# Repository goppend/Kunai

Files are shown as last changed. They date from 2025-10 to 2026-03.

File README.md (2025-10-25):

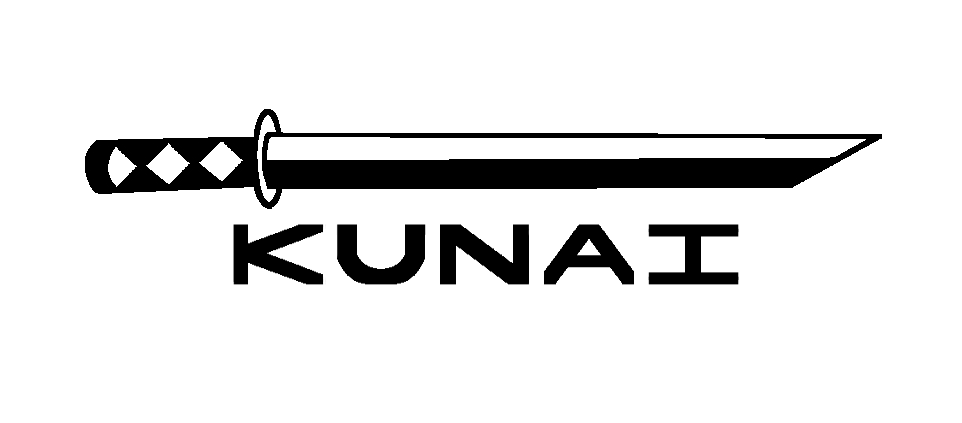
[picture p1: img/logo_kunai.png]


The Kunai is an open source gamepad based on the Raspberry Pi Pico microcontroller.

Its intended use is either as a standalone controller for Playstation and Playstation 2 systems, or integrated into an all-in-one handheld device that uses the aforementioned systems hardware.

Features
---
- A no-compromises approach to emulating the original functions of the Dualshock 2 gamepad.
- 12 inputs that can be configured as either digital or pressure-sensitive analog buttons.
- 2 rumble motor outputs capable of being driven at 256 pulse-width modulated levels.
- Compatible with readily available aftermarket joysticks. Hall-effect joysticks have yet to be tested, but may be compatible.

Compatibility
---
Not enough testing has been performed to discover any major incompatibilities yet, but as the project evolves, this section will be populated with a list of known good and ill-working titles and applications.

To-do
---
Currently, this project is exiting the "functional prototype" phase, and is not especially useful for gaming, but this will change soon. 
- Shrink the prototype PCB down to work as a drop-in replacement for Dualshock controllers.
- Develop a module as small as possible for rapid integration into custom handheld projects. Version 0 of the module has been released! Check it out in the pcb-module directory.

Attribution
---
[Dangiu/PicoMemcard](https://github.com/dangiu/PicoMemcard/) - Credit for the PIO code responsible for doing gamepad/console communication.

[Loc15/PicoGamepadConverter](https://github.com/Loc15/PicoGamepadConverter/) - Much inspiration for this project, and the multi-core implementation.

[GameSX](https://gamesx.com/controldata/psxcont/psxcont.htm) and [Curious Inventor](https://store.curiousinventor.com/guides/PS2)- Excellent documentation on the protocol and data structures.

Ultipryce - Logo artwork.
___
Disclaimer

This is a passion project by a fan and has no affiliation with Sony or the Playstation brand.

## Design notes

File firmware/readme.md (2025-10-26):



## Kunai Firmware
This is the first release of the Kunai Firmware. Only one of its operating modes is mostly complete, and needs more and better testing.

### Building
---
- I recommend using VSCodium with the official Raspberry Pi Pico extension and the latest SDK.
- Open this folder.
- Optionally, edit config.h to suit the hardware.
- Compile.
- Two UF2 artifacts are created in the `build/` directory, `kunai.uf2` for the main PCB, and `kunai-mod.uf2` for the Kunai module.

### Configuration
---
In `config.h`, there are some defines that can be changed to alter the behavior of the Kunai:
- `DIGITAL_INPUTS` If defined, the Kunai will treat inputs as digital button presses rather than analog values from pressure sensors, akin to a Dualshock 2.
- `GPIO_*` The digital I/O pins connected to the Pico. By default, these are tailored to suit the version 0 of either hardware implementation.
- `SPI_*` The pins connected to an SPI analog-to-digital converter, to gather the analog pressure inputs. When configured to be digital-only, these pins are undefined.
- If so desired, changing the host `ACK`, `CLK`, `ATN`, `CMD`, and `DAT` pins requires modification of either of the two `psx-device/psxSPI*.pio` files.

### Future Development
---
- Add proper digital-only input methods. (testing in progress)
- Add a pseudo-analog mode for digital-only hardware to support software that requires analog input.
- Analog/digital mode switching is unimplemented. Not entirely sure how to do this.
- Extensive testing will be needed once the hardware is ready.

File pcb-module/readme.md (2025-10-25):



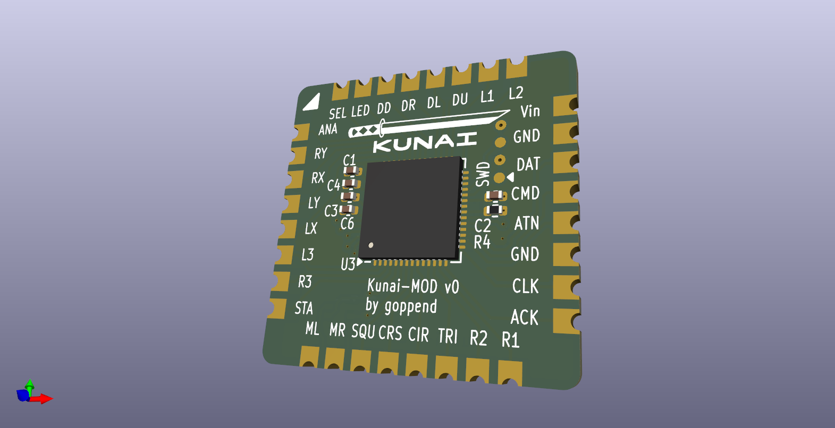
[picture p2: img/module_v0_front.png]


## Module PCB
This is the Kunai, but in a 22 mm x 22 mm module. The intent is to provide a solution for rapid integration into exiting projects. Thus, most of the I/O is dedicated towards direct connections to discrete buttons, though there's no reason a connection to an ADC couldn't be made just like a full-sized Kunai.

There is KiCad footprint `kunai-mod.kicad_mod` available in the root of this directory, which contains the general pinout compatible with the module.

### Future Development
---
- An integration guide for this module. This document will detail the steps necessary to get as much out of the Kunai as possible for your project.
- HD rumble motors as a potential upgrade via e.g. the DRV2603, which is compatible with LRA as well as traditional ERM rumble motors.

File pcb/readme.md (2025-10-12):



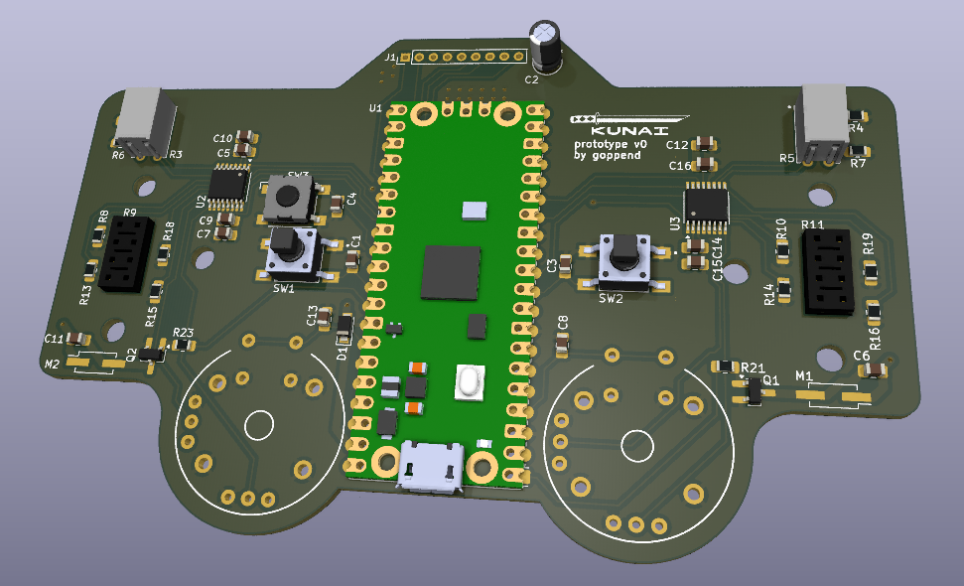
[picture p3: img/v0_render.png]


## Prototype PCB
This is the first release of the Kunai PCB. It's a functional prototype, and as such isn't recommended for gaming yet.

A few things to keep in mind, for anyone interested in building one:
- I have no enclosure designed yet, but the general button layout is 1:1 with an original Dualshock 2.
- The rectangular connectors were for testing, to easily swap a pressure sensor from one spot to another. I would not recommend using these connectors and instead replace the footprint with a normal soldered footprint since that portion of the testing is complete.

### Future Development
---
- Replace aftermarket PS2 joysticks with PS4 since hall effect versions with that footprint exist.
- Replace the Pico with a RP2040.

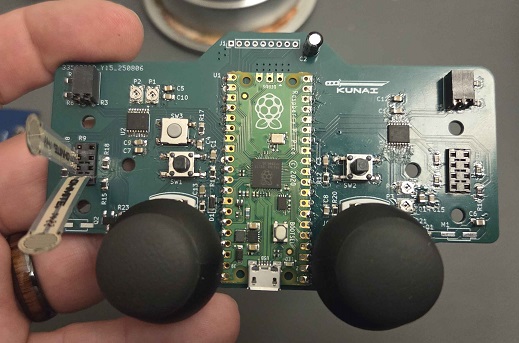
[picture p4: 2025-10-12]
img/prototype.jpg

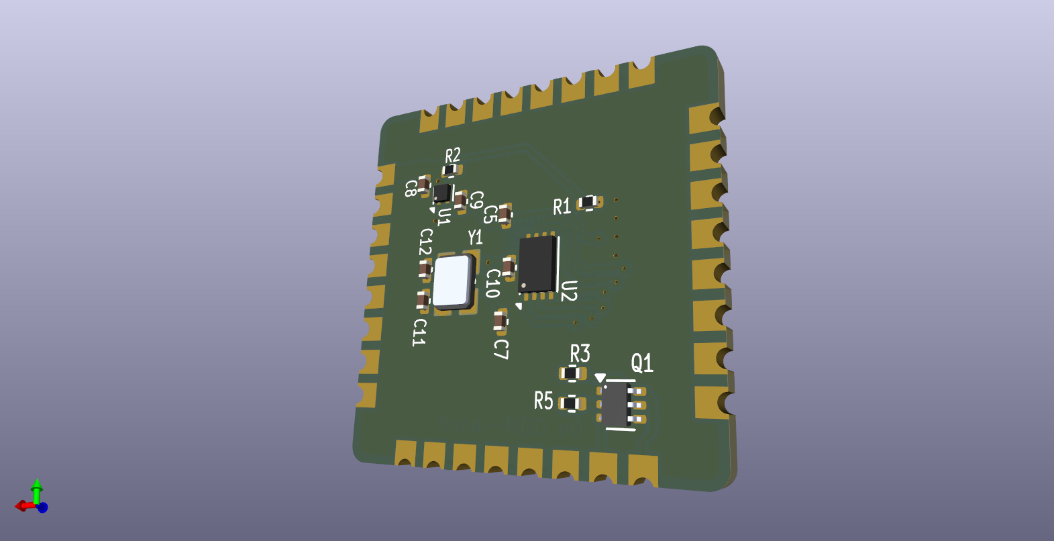
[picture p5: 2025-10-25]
img/module_v0_back.png

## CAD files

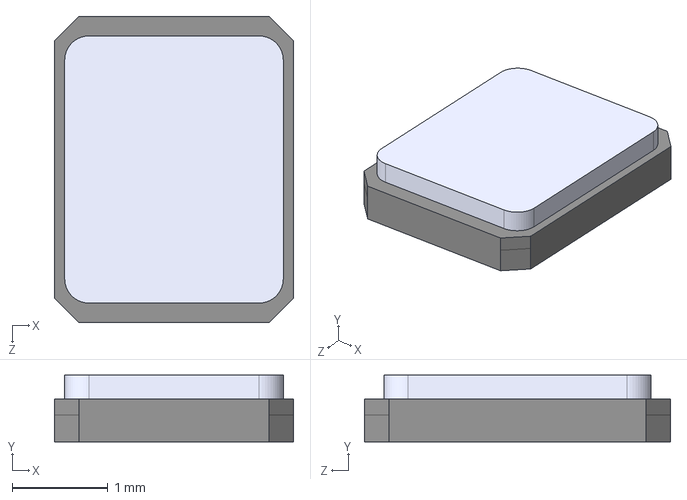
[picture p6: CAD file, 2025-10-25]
pcb-module/3d-models/ABM8-272-T3.step
2.50 x 0.7 x 3.20 mm

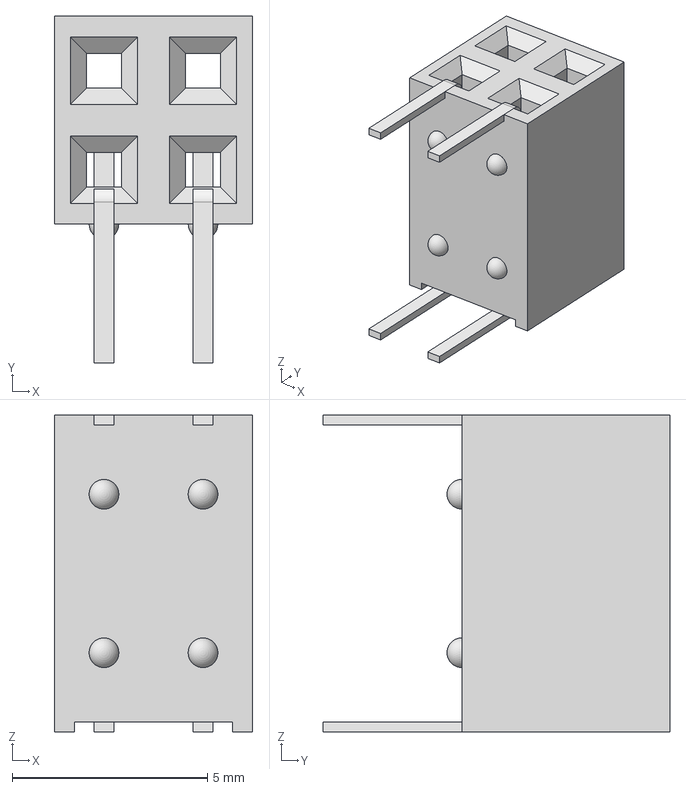
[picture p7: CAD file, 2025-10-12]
pcb/3d-models/BCS-102-L-D-HE.stp
5.08 x 8.89 x 8.13 mm
BCS-102-D-HE_socket
C-95-01-02-L-D-HE
C-95-01-02-L-D-HE2

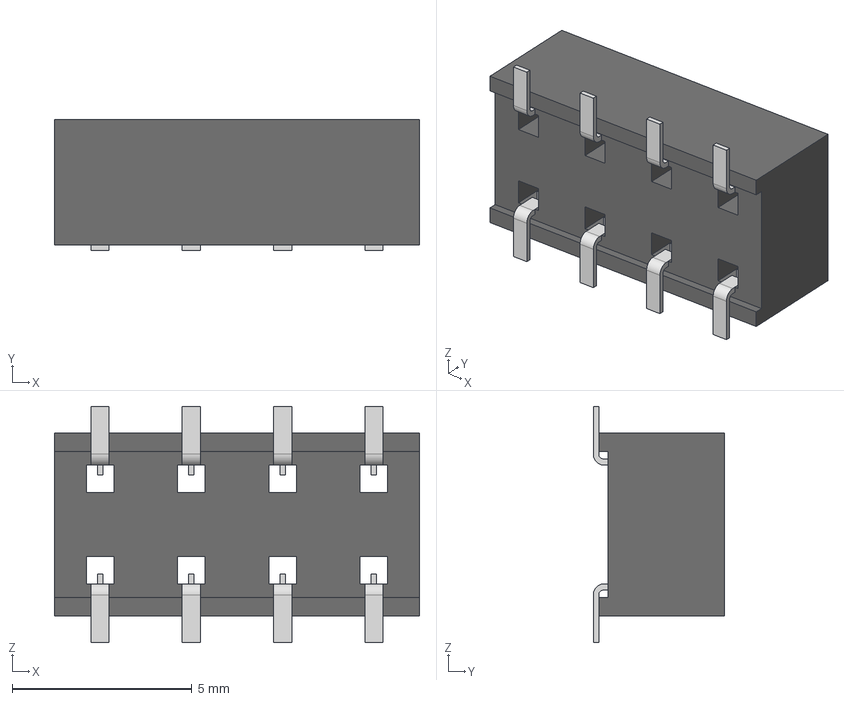
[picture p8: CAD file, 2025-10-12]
pcb/3d-models/HLE-104-02-F-DV-BE.stp
10.2 x 3.66 x 6.58 mm
HLE-104-02-DV_socket
C-132-12-04-F-DV
C-132-12-04-F-DV2

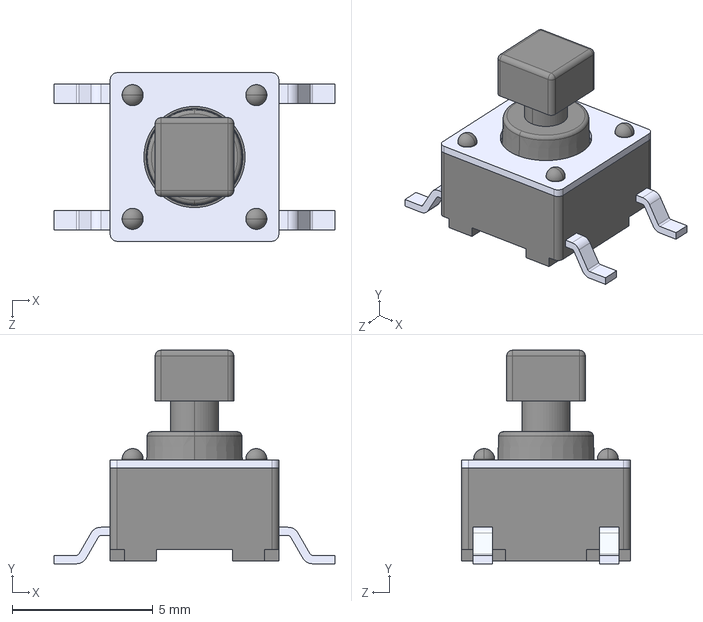
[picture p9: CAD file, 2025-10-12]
pcb/3d-models/TL3301SPF160QG.step
10.0 x 7.60 x 6.00 mm

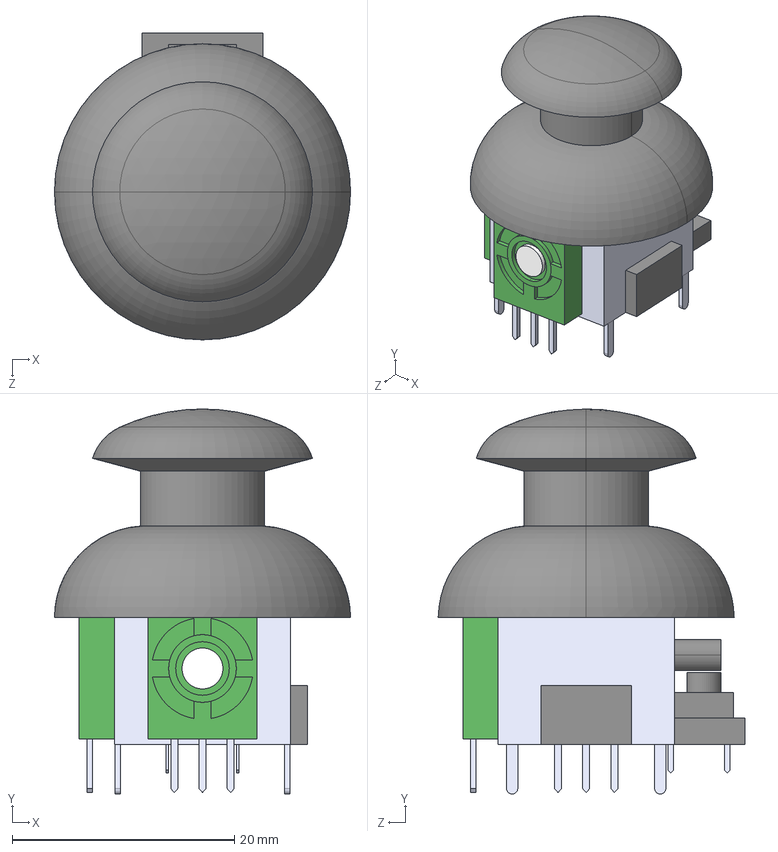
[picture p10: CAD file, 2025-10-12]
pcb/3d-models/COM-09032.step
26.7 x 34.7 x 27.6 mm

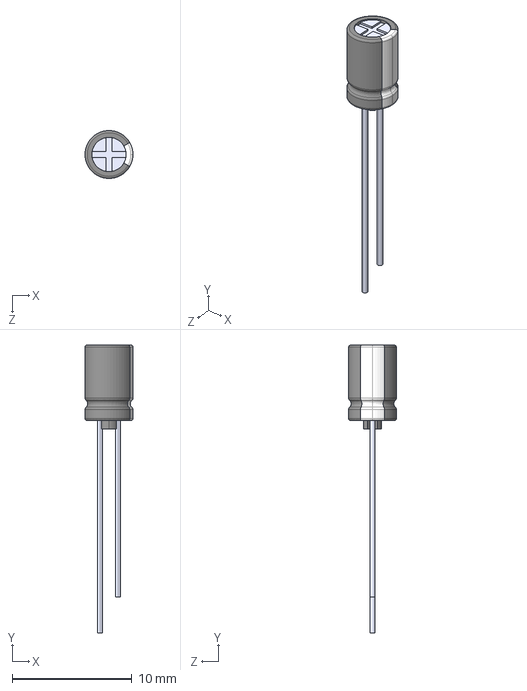
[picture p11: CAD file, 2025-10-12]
pcb/3d-models/ECE-A1EKA100.step
4.00 x 24.0 x 4.00 mm

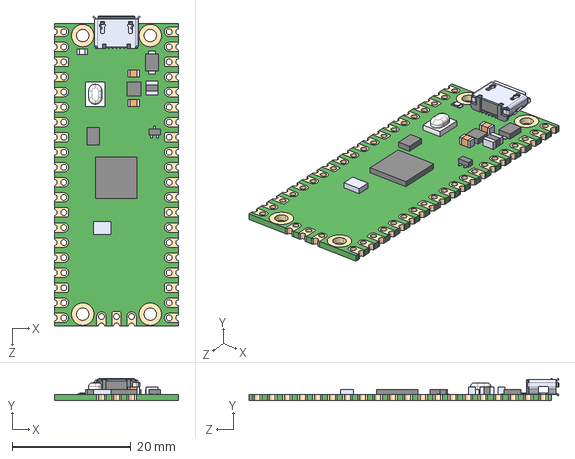
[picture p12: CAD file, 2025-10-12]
pcb/3d-models/SC0915.STEP
21.0 x 3.73 x 52.3 mm

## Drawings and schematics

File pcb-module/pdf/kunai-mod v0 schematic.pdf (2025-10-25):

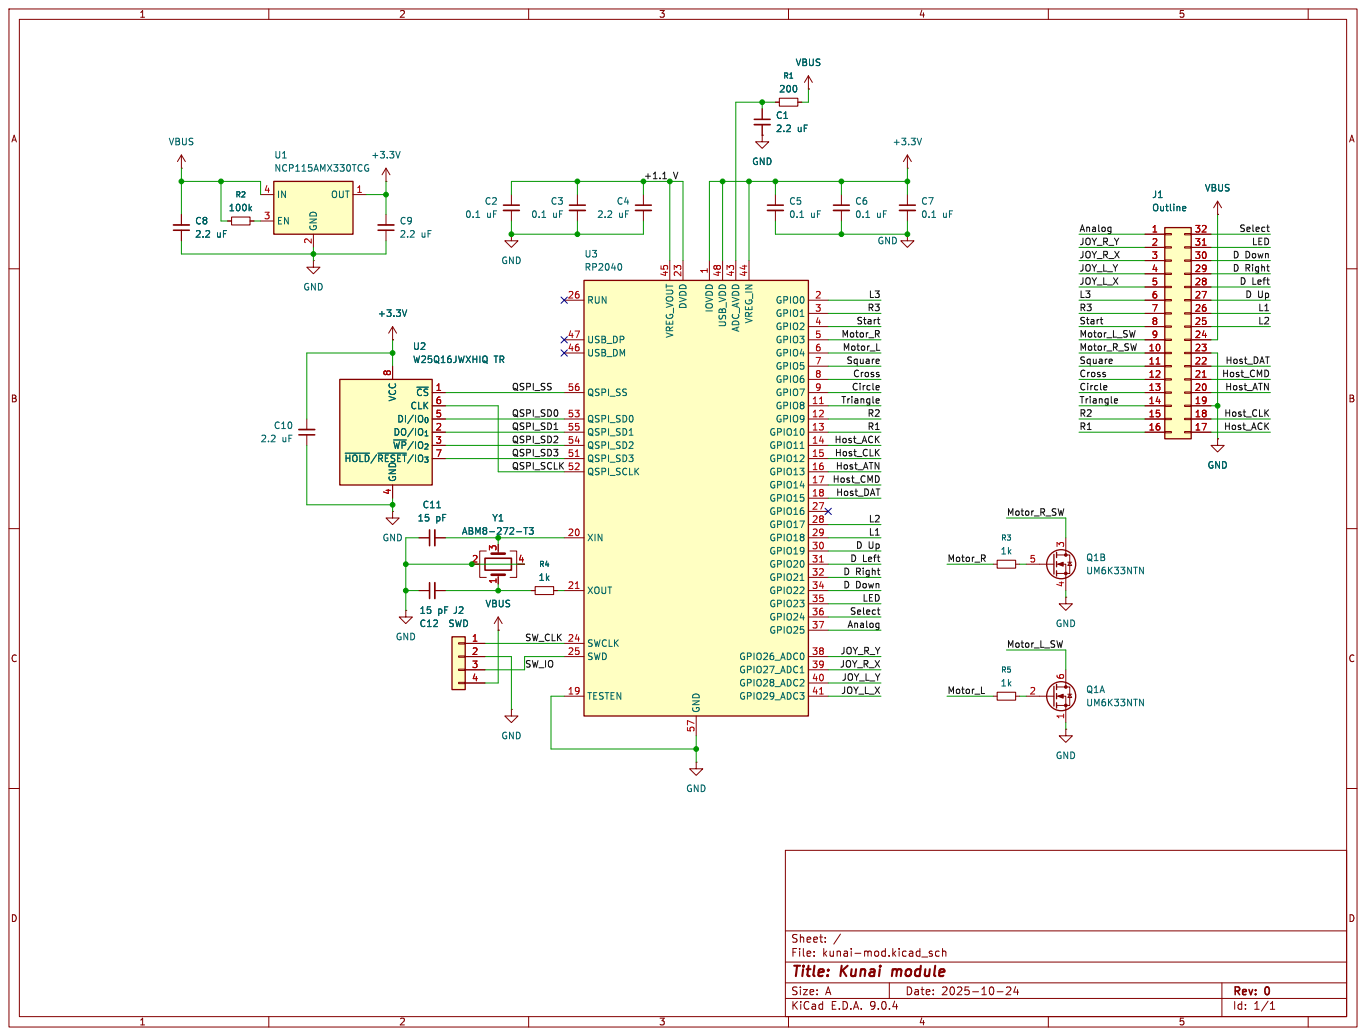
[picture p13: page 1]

1 USB_VDD 48 ADC_AVDD 43 VREG_IN 44 GPIO0 2 GPIO1 3 GPIO2 4 GPIO3 5 GPIO4 6 GPIO5 7 GPIO6 8 GPIO7 9 GPIO8 11 GPIO9 12 GPIO10 13 GPIO11 14 GPIO12 15 GPIO13 16 GPIO14 17 GPIO15 18 GPIO16 27 GPIO17 28 GPIO18 29 GPIO19 30 GPIO20 31 GPIO21 32 GPIO22 34 GPIO23 35 GPIO24 36 GPIO25 37 GPIO26_ADC0 38 GPIO27_ADC1 39 GPIO28_ADC2 40 GPIO29_ADC3 41 U3 RP2040 GND GND GND GND

File: kunai-mod.kicad_sch Sheet: /
Id: 1/1 Title: Kunai module

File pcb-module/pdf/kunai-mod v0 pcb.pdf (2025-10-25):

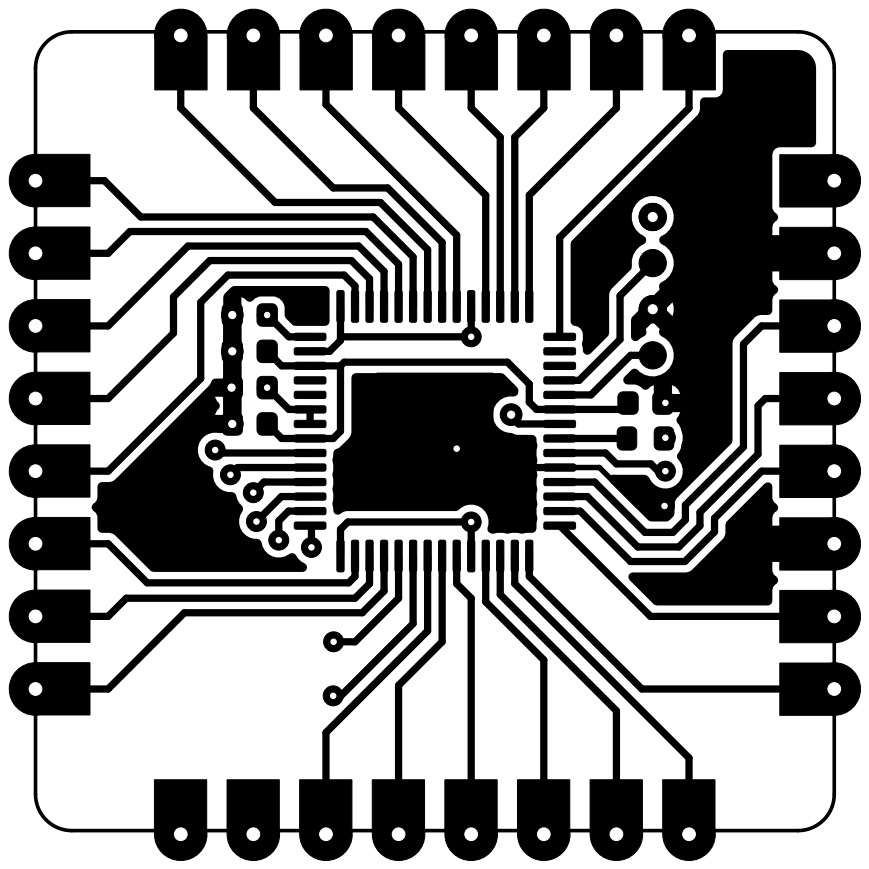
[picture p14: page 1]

File: kunai-mod.kicad_pcb Sheet: Top Copper

Id: 1/8 Title: Kunai Module

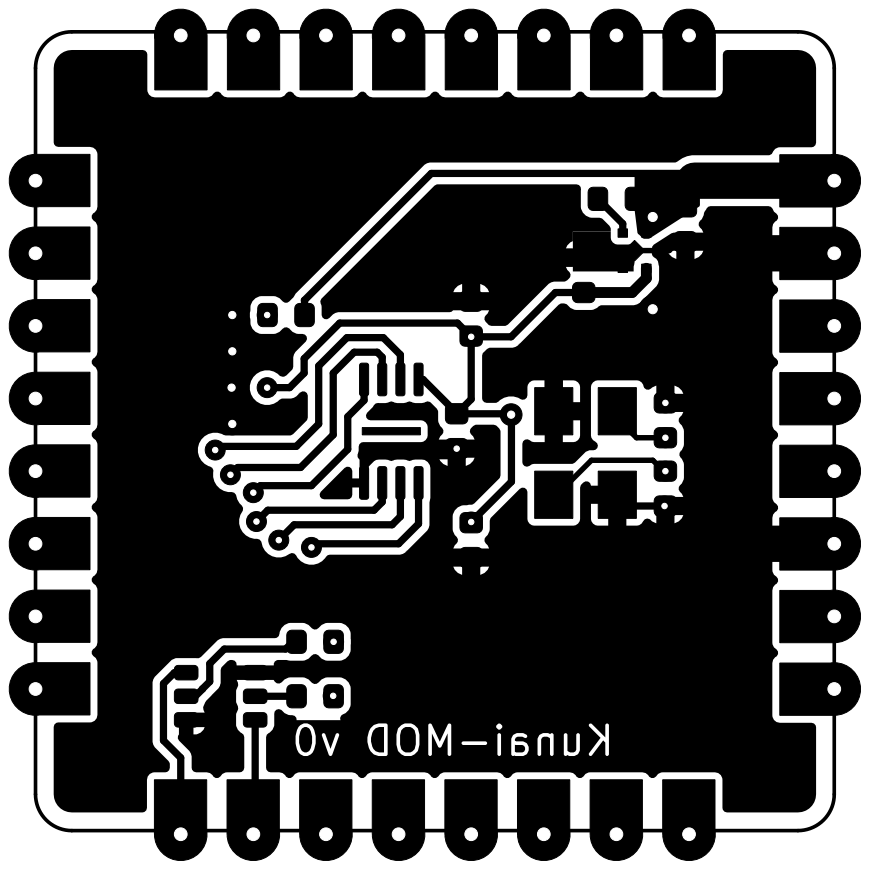
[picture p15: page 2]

File: kunai-mod.kicad_pcb Sheet: Bottom Copper

Id: 2/8 Title: Kunai Module

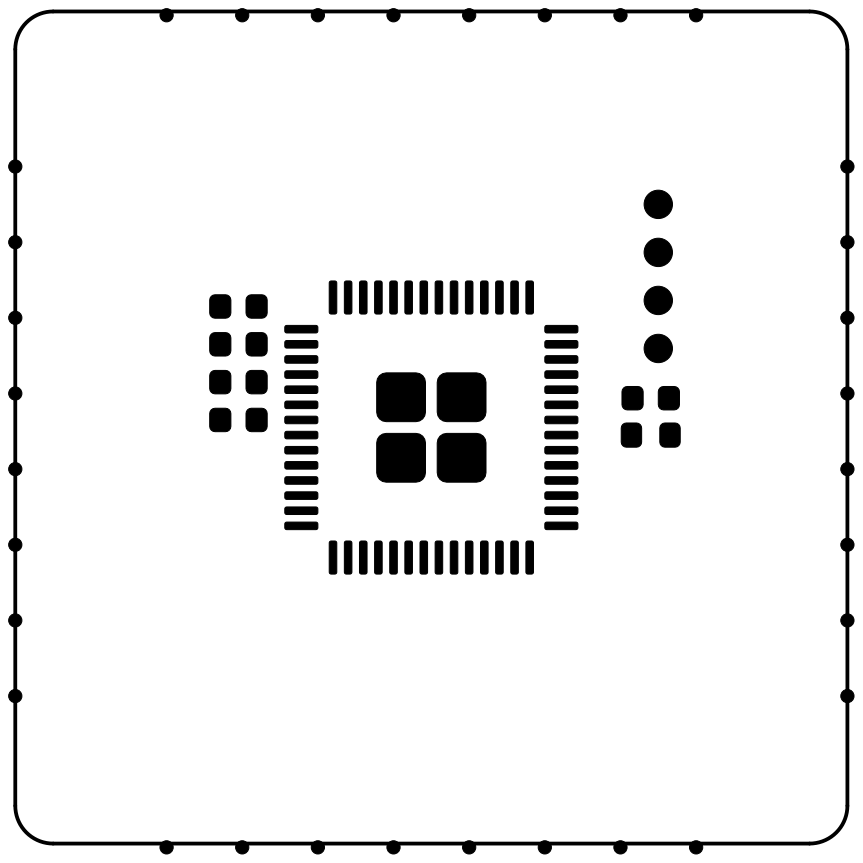
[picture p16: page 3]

Id: 3/8 Title: Kunai Module

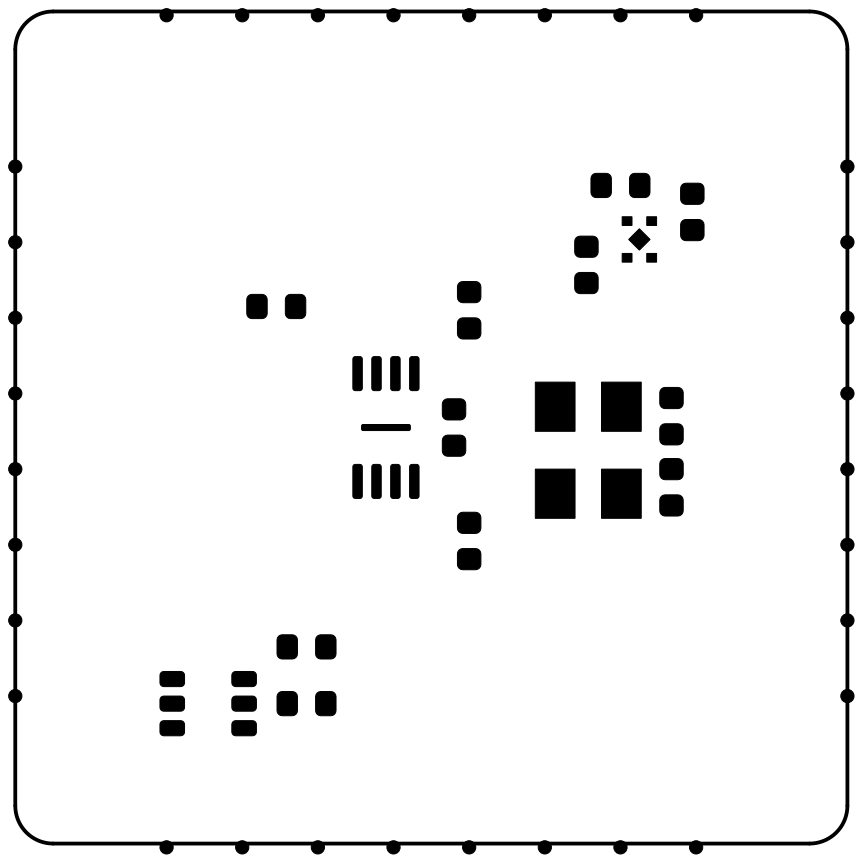
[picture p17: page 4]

Id: 4/8 Title: Kunai Module

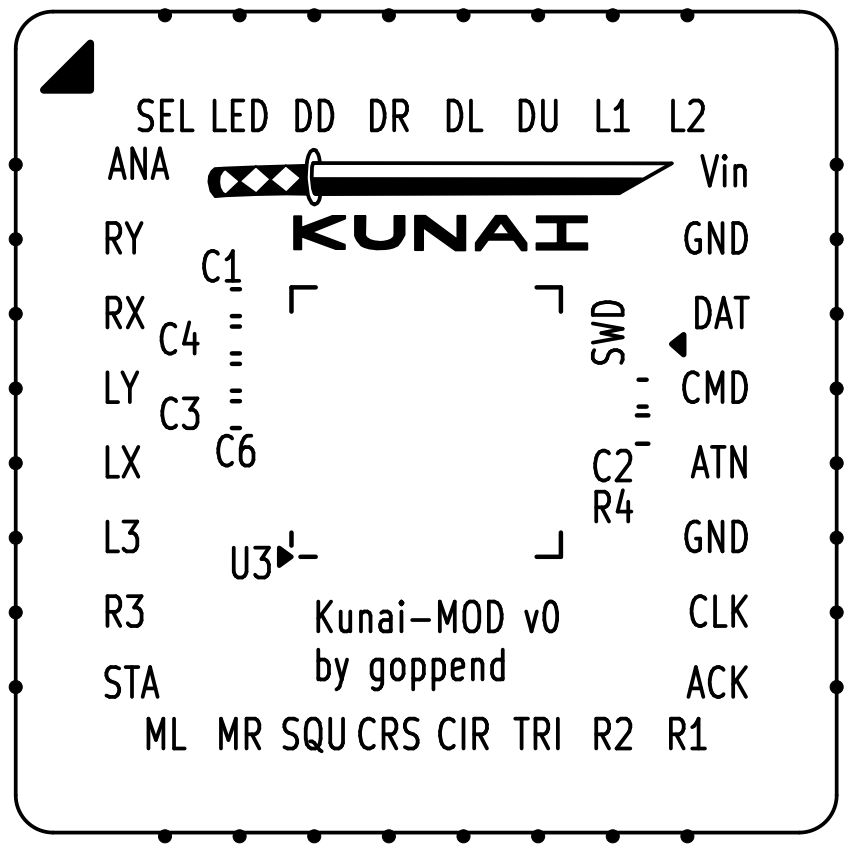
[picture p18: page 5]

Kunai-MOD v0 by goppend

File: kunai-mod.kicad_pcb Sheet: Top Overlay

Id: 5/8 Title: Kunai Module

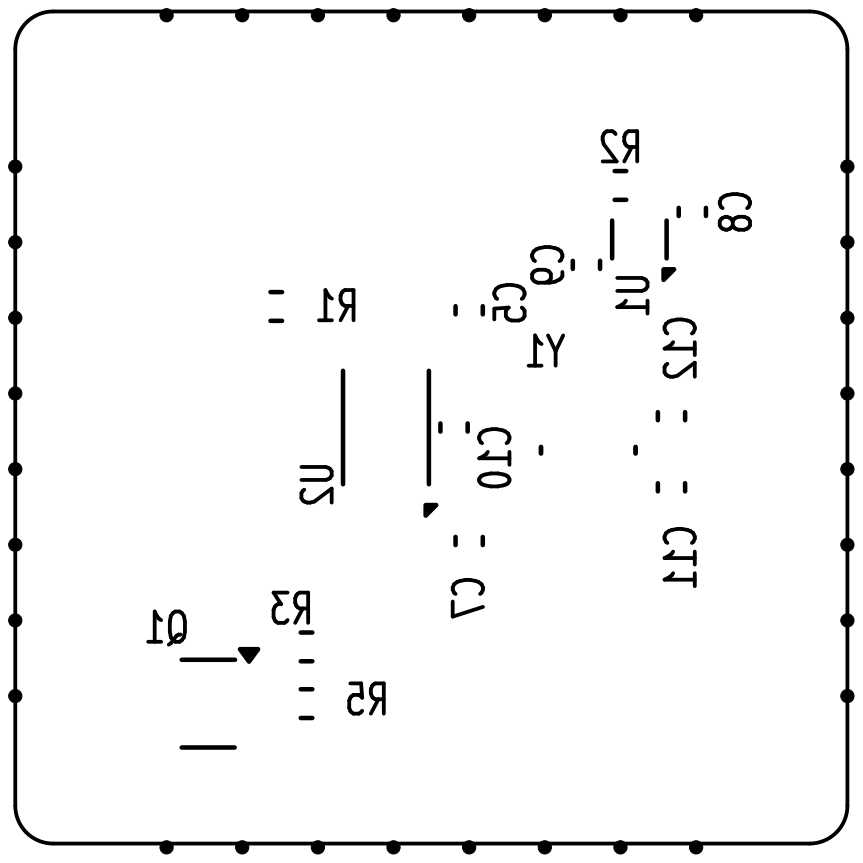
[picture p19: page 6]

Id: 6/8 Title: Kunai Module

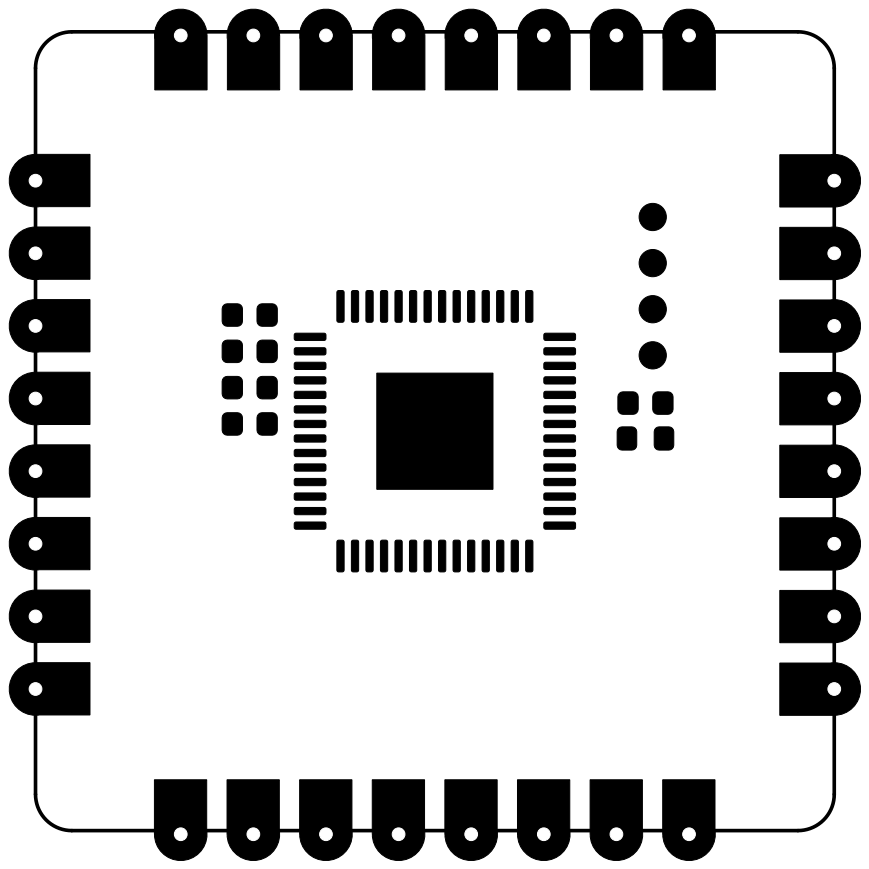
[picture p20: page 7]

File: kunai-mod.kicad_pcb Sheet: Top Soldermask

Id: 7/8 Title: Kunai Module

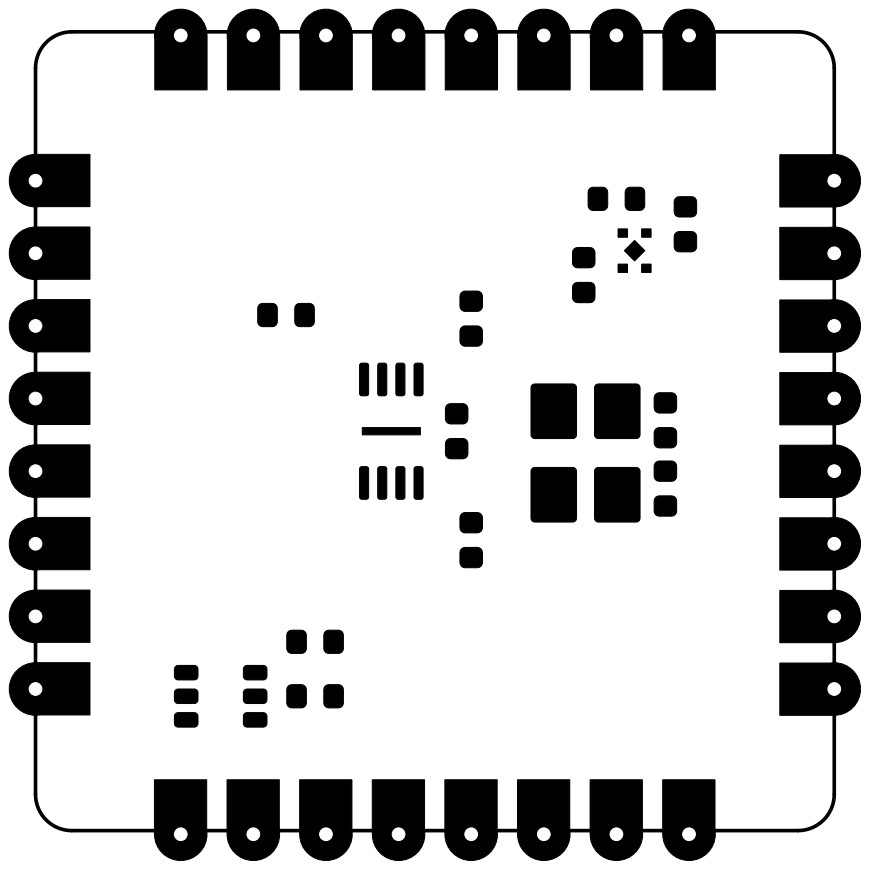
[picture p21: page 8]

File: kunai-mod.kicad_pcb Sheet: Bottom Soldermask

Id: 8/8 Title: Kunai Module

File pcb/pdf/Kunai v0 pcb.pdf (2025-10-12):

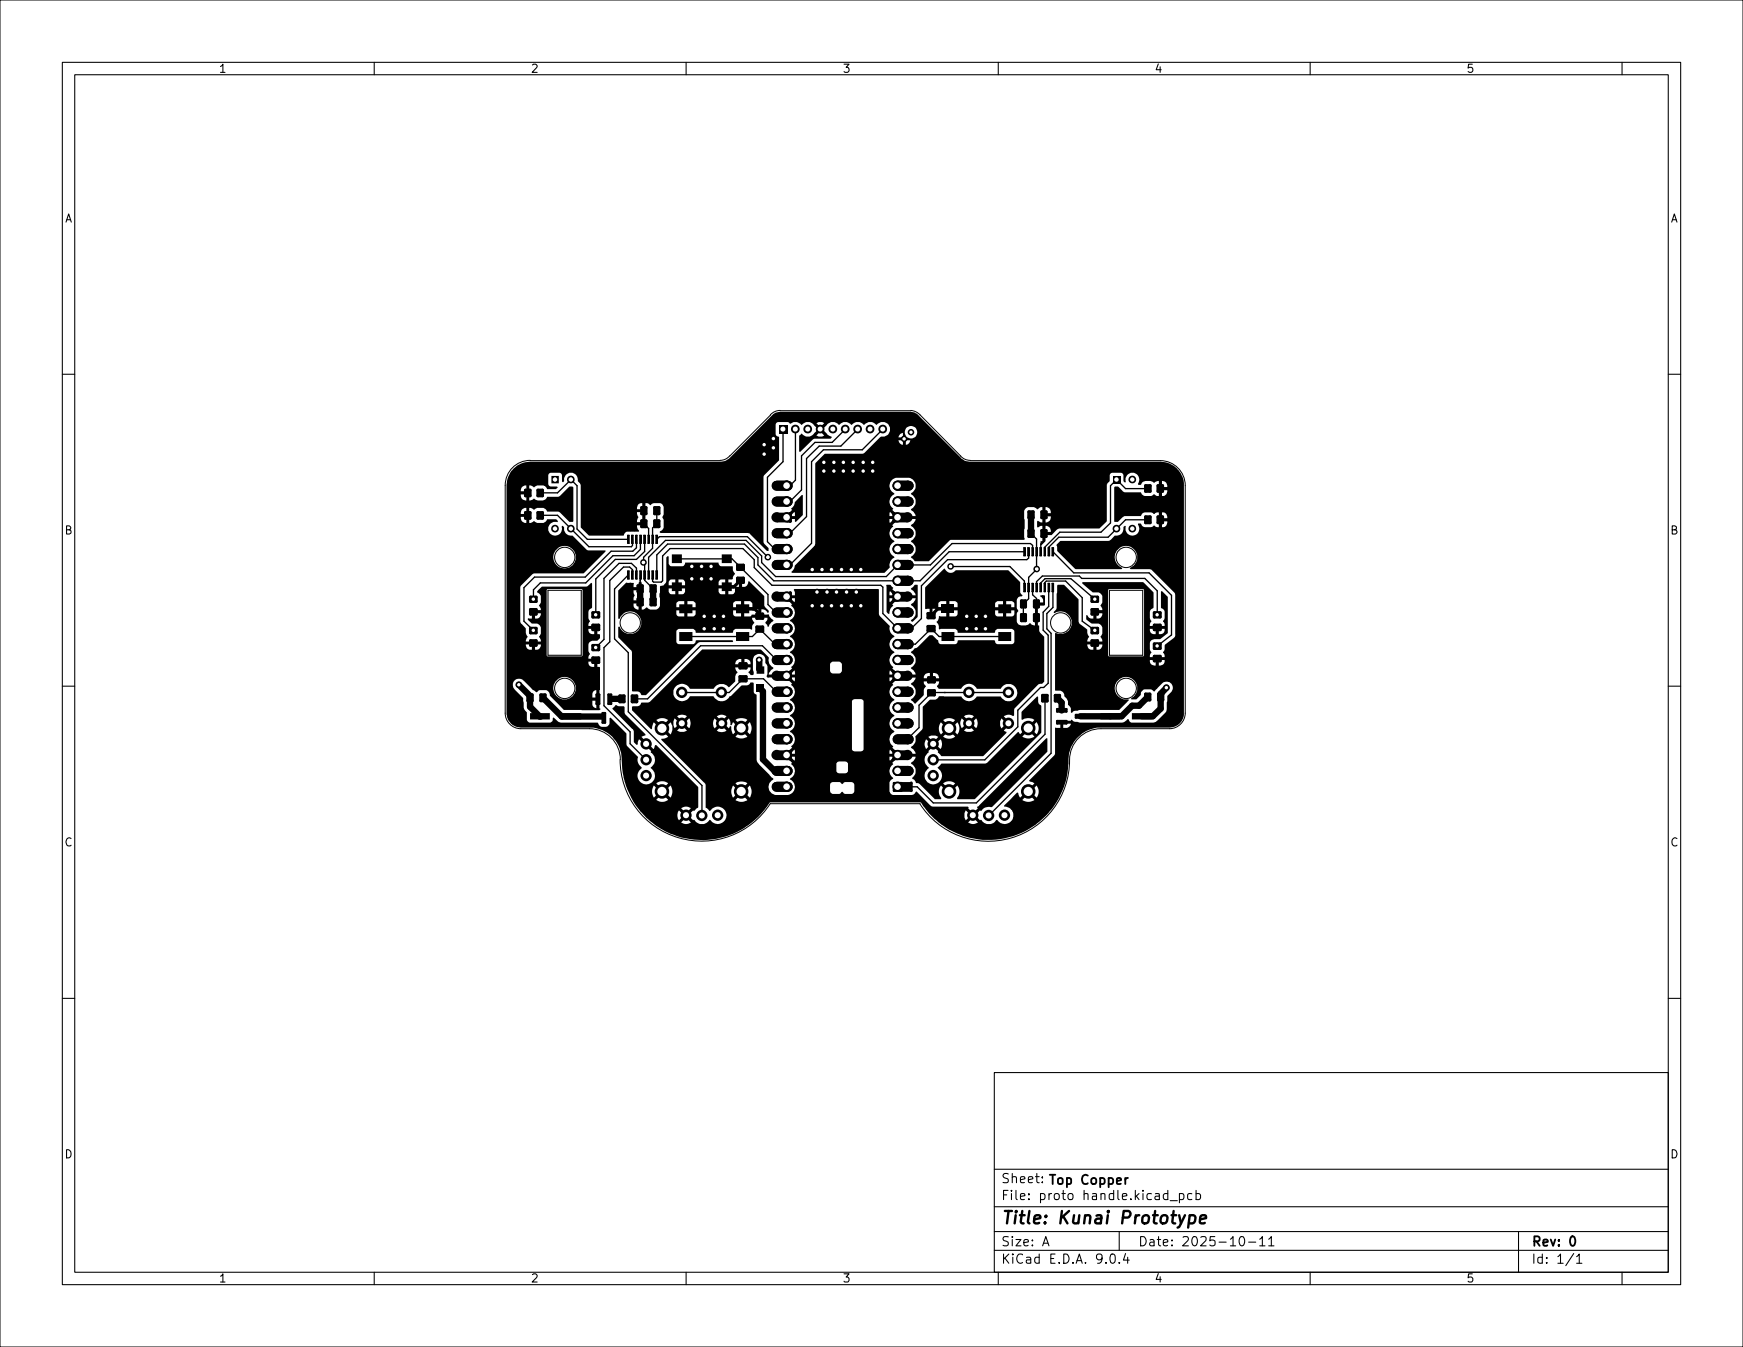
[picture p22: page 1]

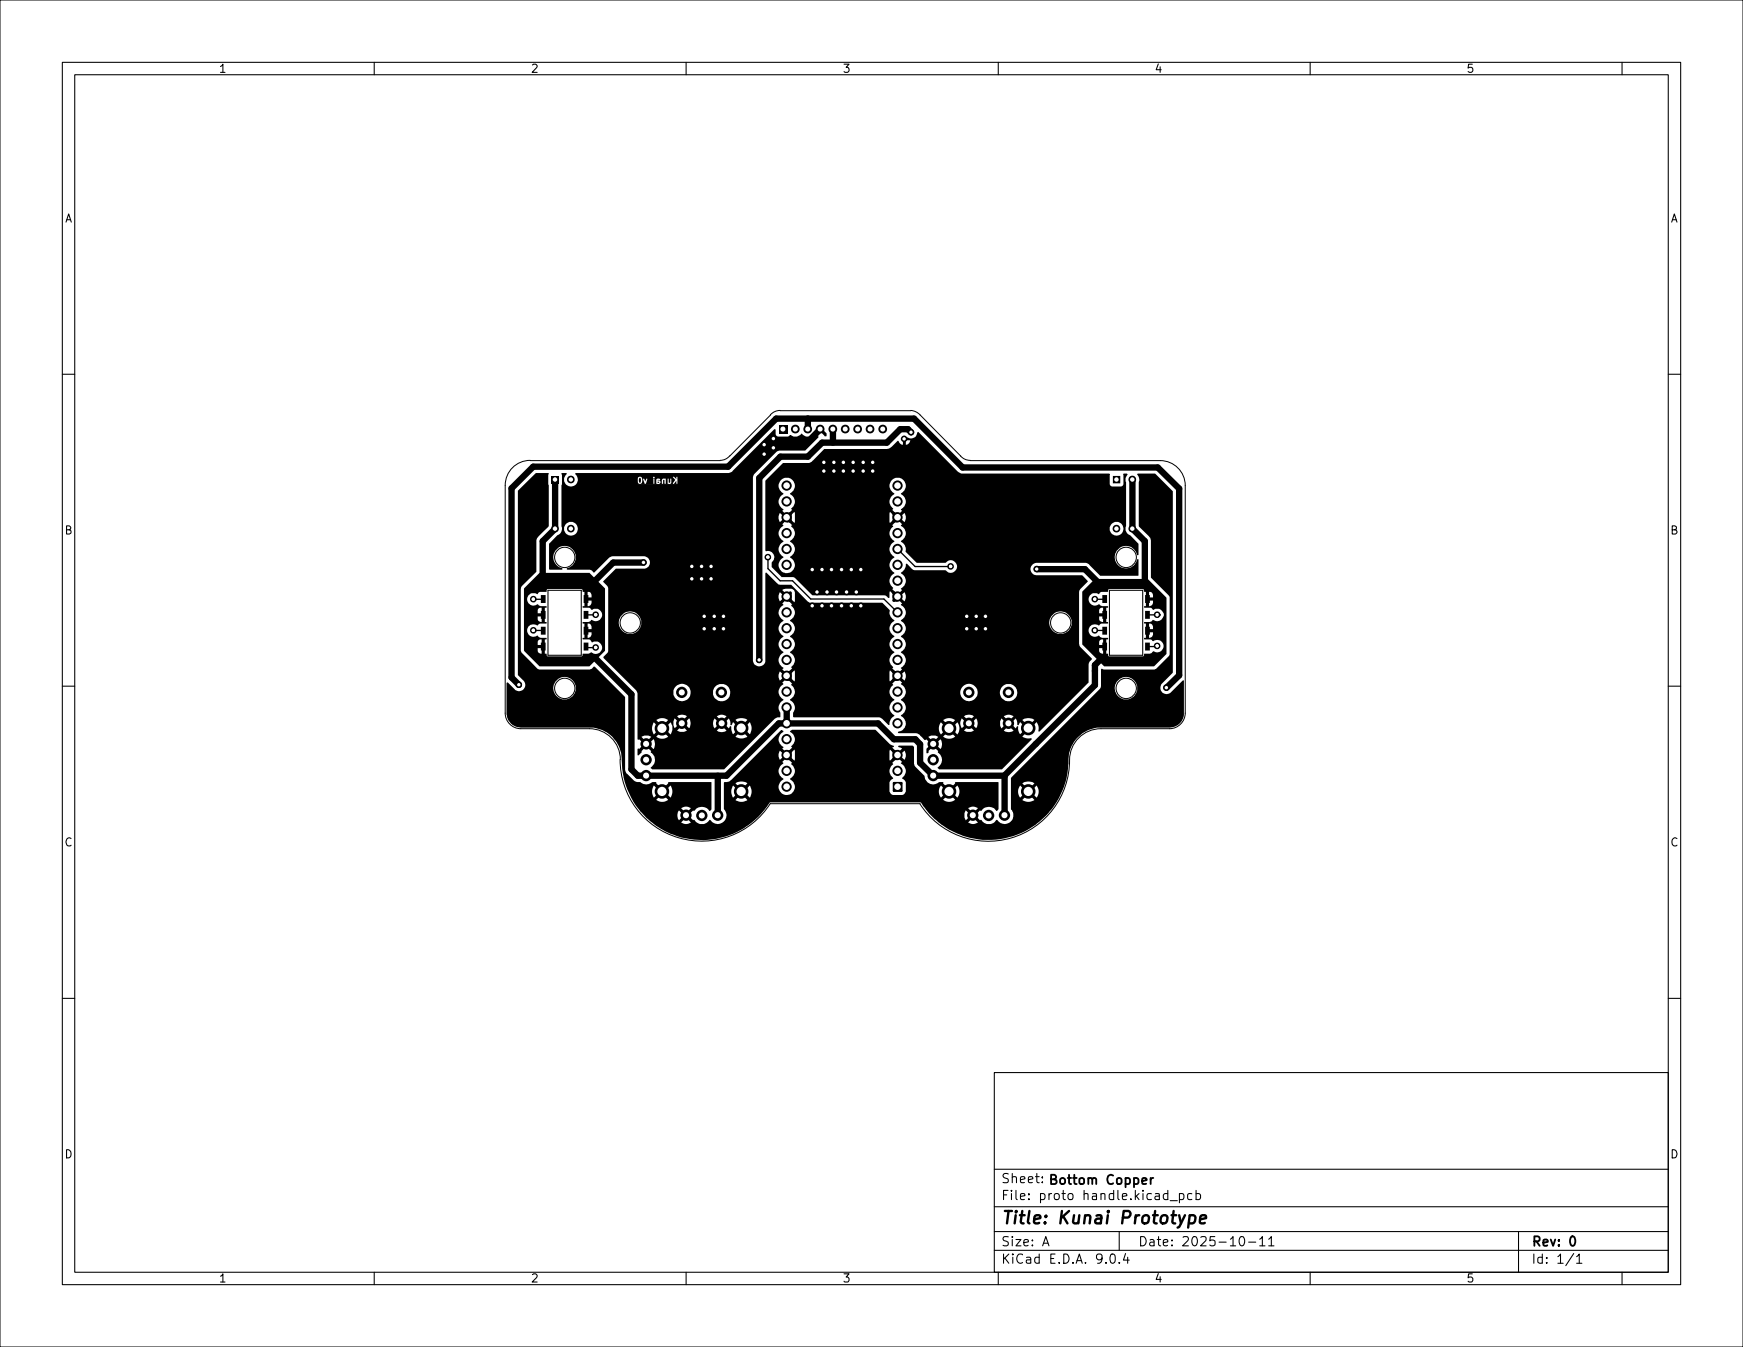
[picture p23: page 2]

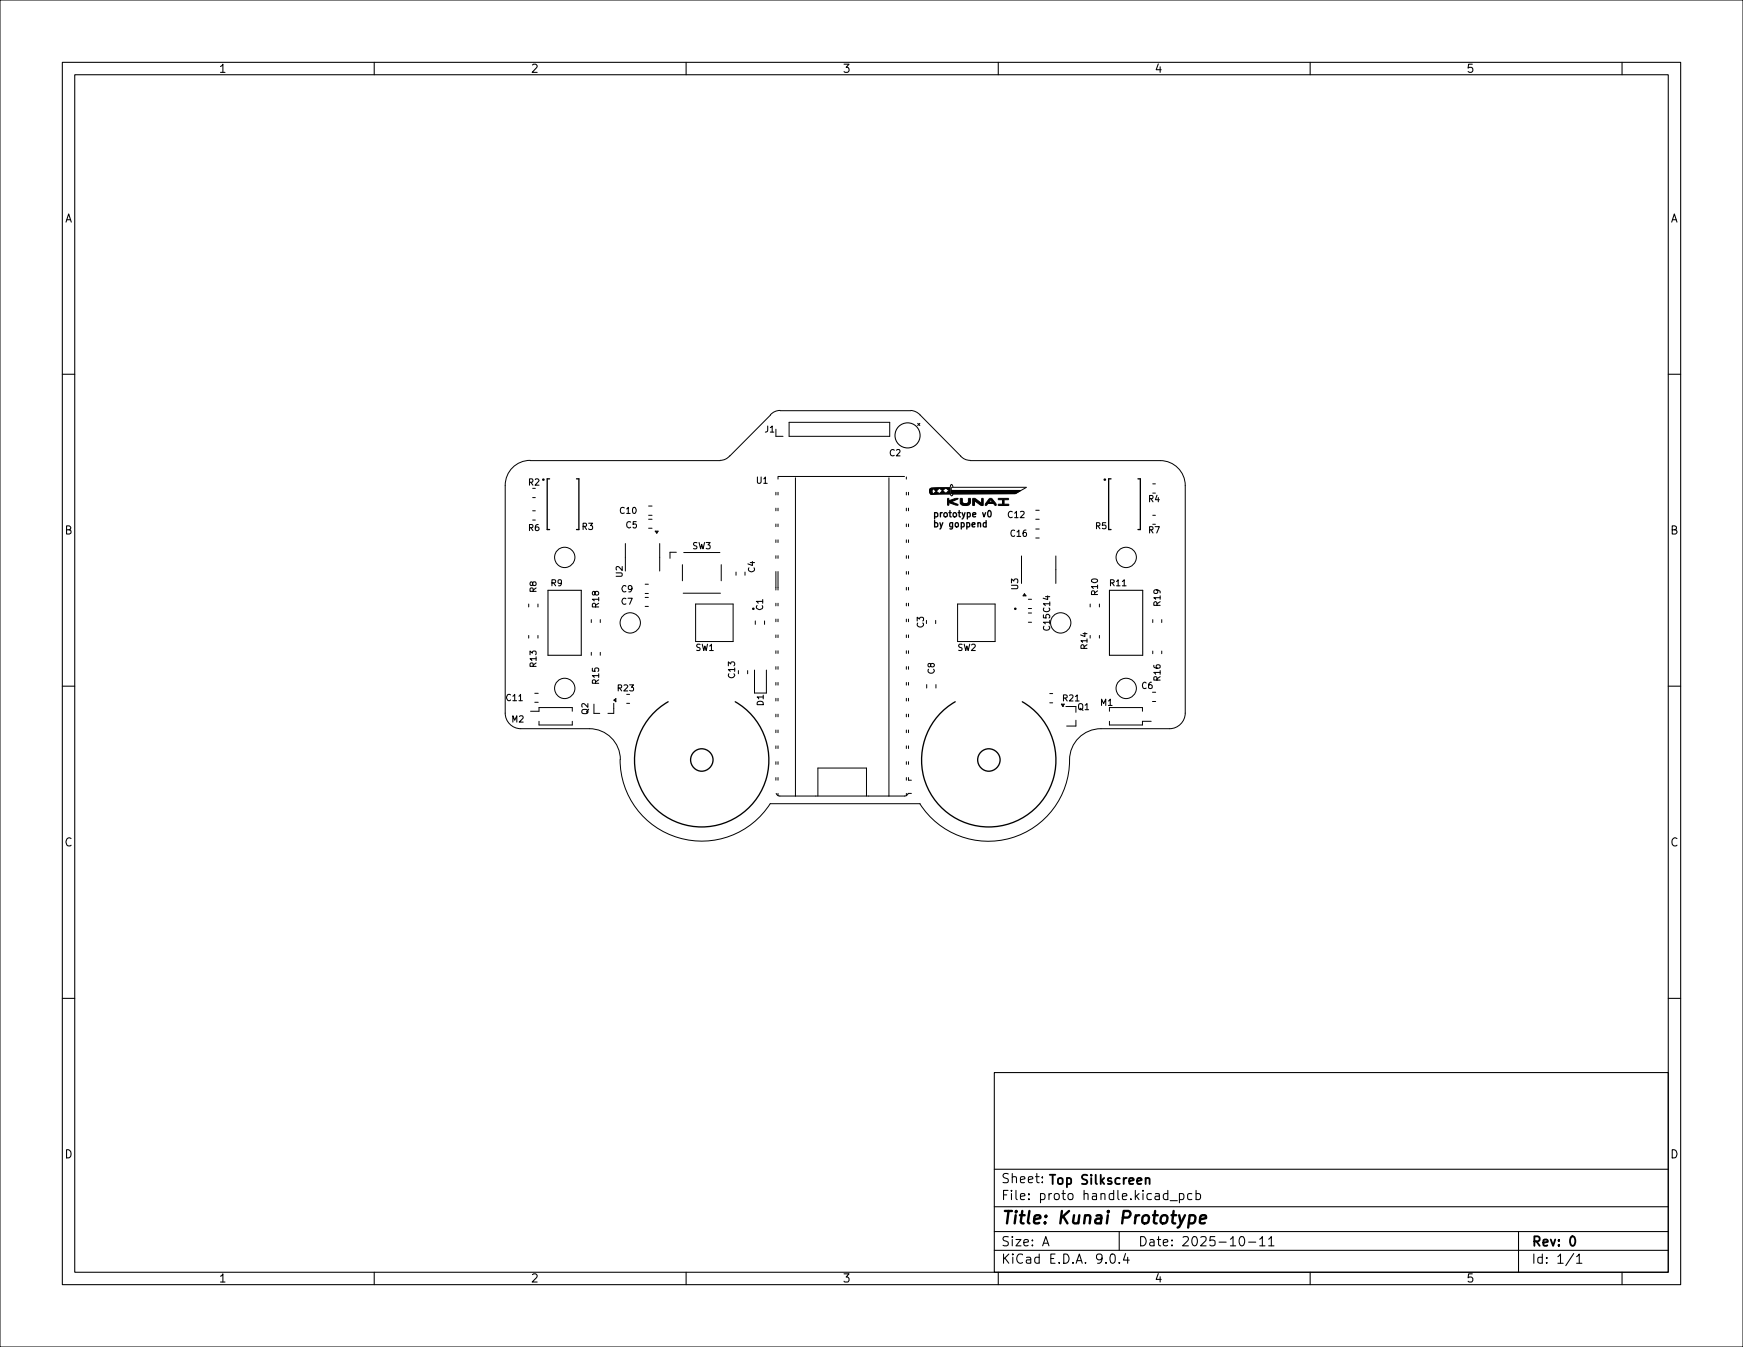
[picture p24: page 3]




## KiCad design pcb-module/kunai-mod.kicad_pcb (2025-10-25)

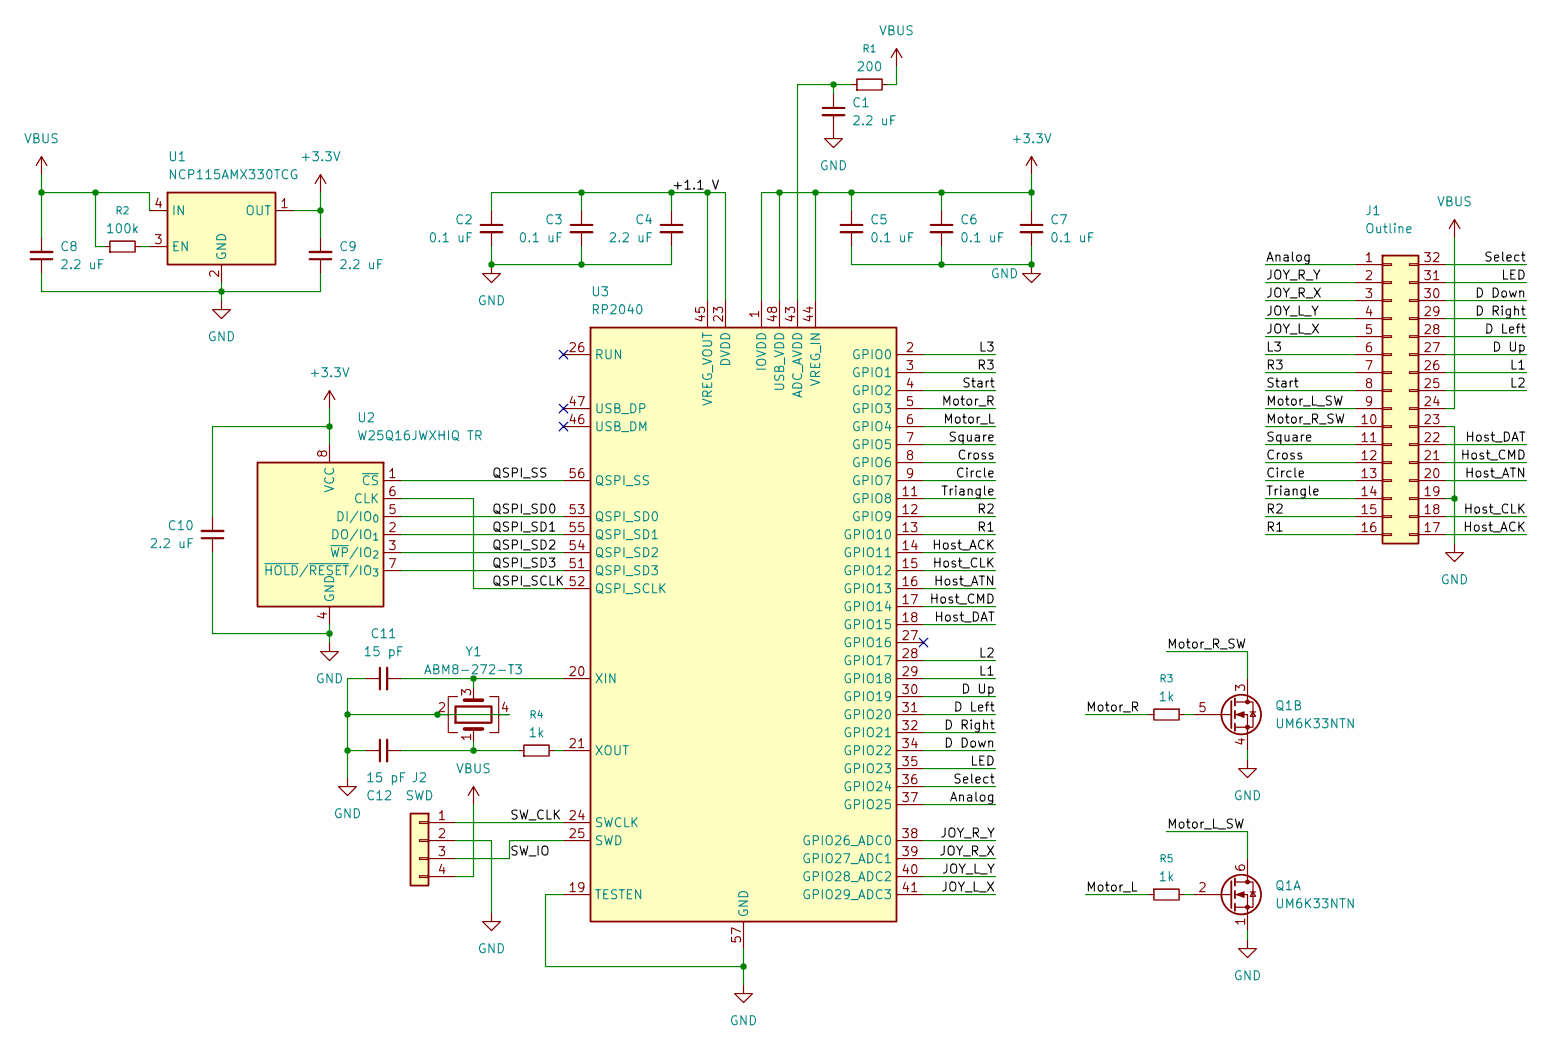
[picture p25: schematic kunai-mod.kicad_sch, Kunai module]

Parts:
C1, C4, C8, C9, C10: 2.2 uF; C_0402_1005Metric; part number CC0402KRX5R7BB225; LCSC Part # C170151
C2, C3, C5, C6, C7: 0.1 uF; C_0402_1005Metric; part number C0402C104K4RACTU; LCSC Part # C169842
C11, C12: 15 pF; C_0402_1005Metric; part number CC0402JRNPO8BN150; LCSC Part # C541359
J1: Outline; Kunai-mod-outline; part number N/A; LCSC Part # N/A
J2: SWD; 1x04 1.27mm test point; part number N/A; LCSC Part # N/A
Q1: UM6K33NTN; SOT-363_SC-70-6; part number UM6K33NTN; LCSC Part # C2926471
R1: 200; R_0402_1005Metric; part number RC0402FR-07200RL; LCSC Part # C114764
R2: 100k; R_0402_1005Metric; part number RC0402JR-07100KL; LCSC Part # C106234
R3, R4, R5: 1k; R_0402_1005Metric; part number RC0402JR-071KL; LCSC Part # C105637
U1: NCP115AMX330TCG; XDFN4-JLC; part number NCP115AMX330TCG; LCSC Part # C603503
U2: W25Q16JWXHIQ TR; Winbond_USON-8-1EP_3x2mm_P0.5mm_EP0.2x1.6mm; part number W25Q16JWXHIQ TR; LCSC Part # C2835333
U3: RP2040; QFN-56-1EP_7x7mm_P0.4mm_EP3.2x3.2mm; part number RP2040; LCSC Part # C2040
Y1: ABM8-272-T3; XTAL_ABM8-272-T3; part number ABM8-272-T3; LCSC Part # C20625731

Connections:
+3.3V: C5.1, C6.1, C7.1, C9.2, C10.2, U1.1 (OUT), U2.8 (VCC), U3.1 (IOVDD), U3.10 (IOVDD), U3.22 (IOVDD), U3.33 (IOVDD), U3.42 (IOVDD), U3.44 (VREG_IN), U3.48 (USB_VDD), U3.49 (IOVDD)
/+1.1 V: C2.1, C3.1, C4.1, U3.23 (DVDD), U3.45 (VREG_VOUT), U3.50 (DVDD)
/Analog: J1.1, U3.37 (GPIO25)
/Circle: J1.13, U3.9 (GPIO7)
/Cross: J1.12, U3.8 (GPIO6)
/D Down: J1.30, U3.34 (GPIO22)
/D Left: J1.28, U3.31 (GPIO20)
/D Right: J1.29, U3.32 (GPIO21)
/D Up: J1.27, U3.30 (GPIO19)
/Host_ACK: J1.17, U3.14 (GPIO11)
/Host_ATN: J1.20, U3.16 (GPIO13)
/Host_CLK: J1.18, U3.15 (GPIO12)
/Host_CMD: J1.21, U3.17 (GPIO14)
/Host_DAT: J1.22, U3.18 (GPIO15)
/JOY_L_X: J1.5, U3.41 (GPIO29_ADC3)
/JOY_L_Y: J1.4, U3.40 (GPIO28_ADC2)
/JOY_R_X: J1.3, U3.39 (GPIO27_ADC1)
/JOY_R_Y: J1.2, U3.38 (GPIO26_ADC0)
/L1: J1.26, U3.29 (GPIO18)
/L2: J1.25, U3.28 (GPIO17)
/L3: J1.6, U3.2 (GPIO0)
/LED: J1.31, U3.35 (GPIO23)
/Motor_L: R5.1, U3.6 (GPIO4)
/Motor_L_SW: J1.9, Q1.6 (D)
/Motor_R: R3.2, U3.5 (GPIO3)
/Motor_R_SW: J1.10, Q1.3 (D)
/QSPI_SCLK: U2.6 (CLK), U3.52 (QSPI_SCLK)
/QSPI_SD0: U2.5 (DI/IO_{0}), U3.53 (QSPI_SD0)
/QSPI_SD1: U2.2 (DO/IO_{1}), U3.55 (QSPI_SD1)
/QSPI_SD2: U2.3 (~WP/IO_{2}), U3.54 (QSPI_SD2)
/QSPI_SD3: U2.7 (~HOLD/~RESET/IO_{3}), U3.51 (QSPI_SD3)
/QSPI_SS: U2.1 (~CS), U3.56 (QSPI_SS)
/R1: J1.16, U3.13 (GPIO10)
/R2: J1.15, U3.12 (GPIO9)
/R3: J1.7, U3.3 (GPIO1)
/SW_CLK: J2.1, U3.24 (SWCLK)
/SW_IO: J2.3, U3.25 (SWD)
/Select: J1.32, U3.36 (GPIO24)
/Square: J1.11, U3.7 (GPIO5)
/Start: J1.8, U3.4 (GPIO2)
/Triangle: J1.14, U3.11 (GPIO8)
GND: C1.2, C2.2, C3.2, C4.2, C5.2, C6.2, C7.2, C8.1, C9.1, C10.1, C11.1, C12.1, J1.19, J1.23, J2.2, Q1.1 (S), Q1.4 (S), U1.2 (GND), U1.5 (GND), U2.4 (GND), U3.19 (TESTEN), U3.57 (GND), Y1.2, Y1.4
unnamed: C12.2, R4.1, Y1.1
unnamed: Q1.2 (G), R5.2
unnamed: Q1.5 (G), R3.1
unnamed: R2.2, U1.3 (EN)
unnamed: C1.1, R1.1, U3.43 (ADC_AVDD)
unnamed: C11.2, U3.20 (XIN), Y1.3
unnamed: R4.2, U3.21 (XOUT)
VBUS: C8.2, J1.24, J2.4, R1.2, R2.1, U1.4 (IN)

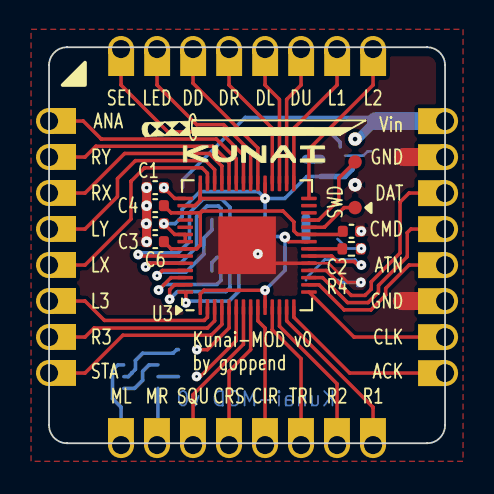
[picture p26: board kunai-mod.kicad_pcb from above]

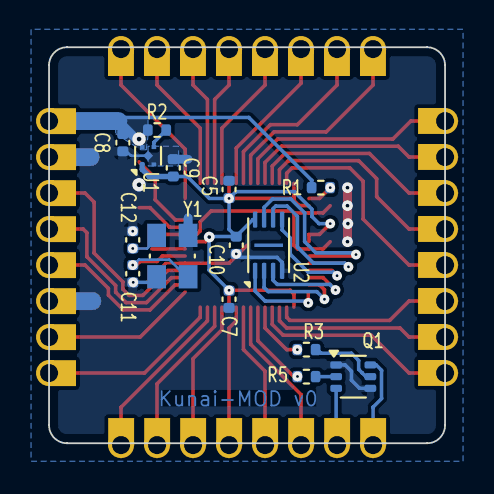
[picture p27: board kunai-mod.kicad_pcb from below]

Board: 2 copper layers, 22.0 x 22.0 mm, 24 parts (15 on the bottom side), 50 nets.

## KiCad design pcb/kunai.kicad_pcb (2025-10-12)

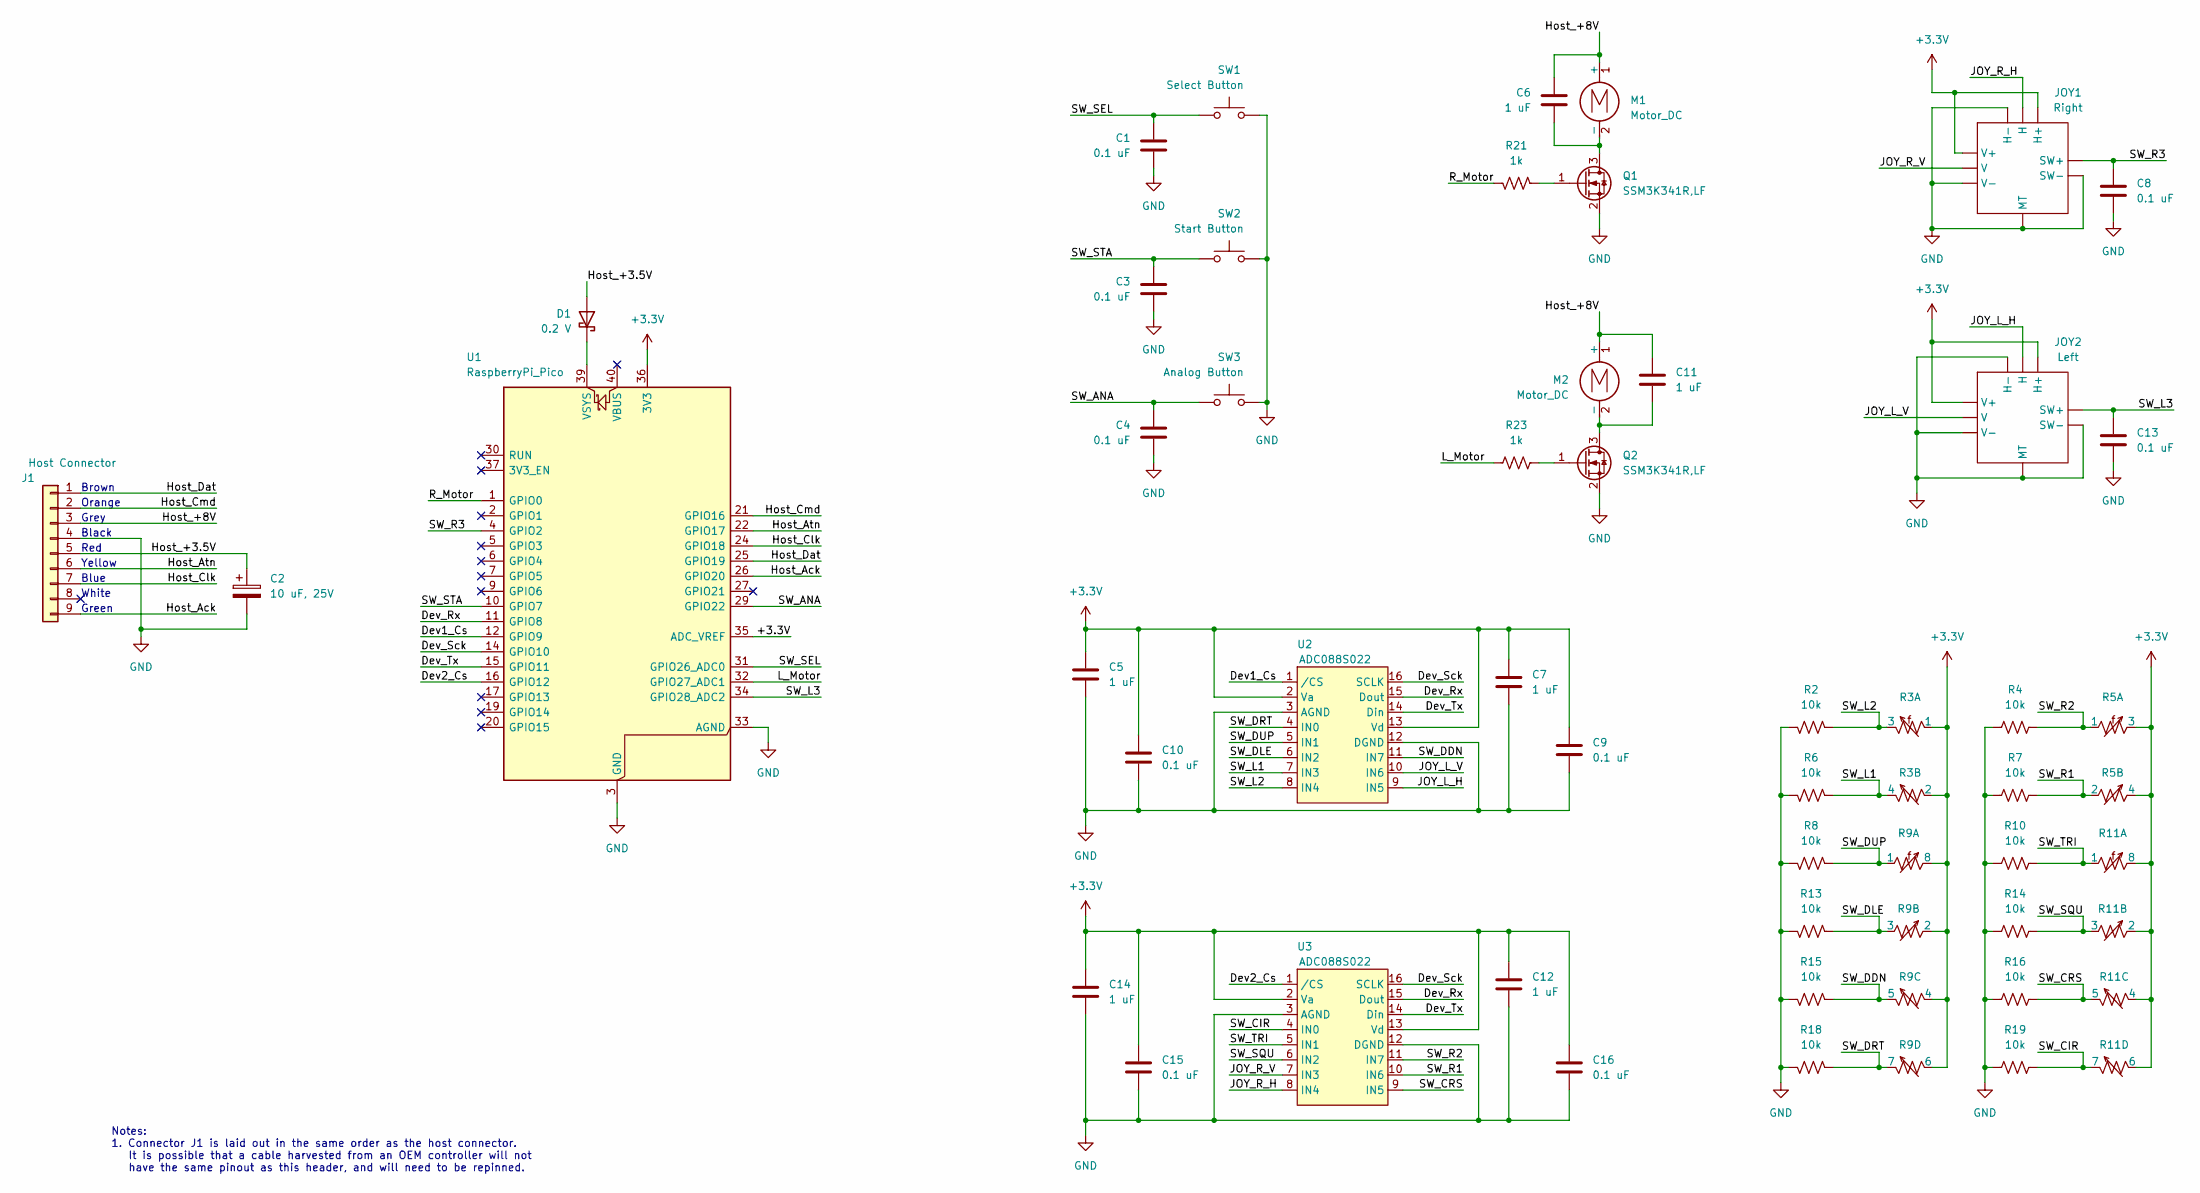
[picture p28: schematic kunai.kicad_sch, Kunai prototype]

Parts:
C1, C3, C4, C8, C9, C10, C13, C15, C16: 0.1 uF; C_0805_2012Metric_Pad1.18x1.45mm_HandSolder; Part Number C0805C104K5RAC7210
C2: 10 uF, 25V; Panasonic ECE-A1EKA100; Part Number ECE-A1EKA100
C5, C7, C12, C14: 1 uF; C_0805_2012Metric_Pad1.18x1.45mm_HandSolder; Part Number C0805C105K3RACTU
C6, C11: 1 uF; C_0805_2012Metric_Pad1.18x1.45mm_HandSolder; Part Number GRJ21BC72A105KE11L
D1: 0.2 V; Nexperia_CFP3_SOD-123W; Part Number MBR120VLSFT1G
J1: Host Connector; PinHeader_1x09_P2.00mm_Vertical; Part Number N/A
JOY1: Right; PS4_joystick; Part Number N/A
JOY2: Left; PS4_joystick; Part Number N/A
M1, M2: Motor_DC; PinHeader_2x01_P2.54mm_Vertical_SMD; Part Number N/A
Q1, Q2: SSM3K341R,LF; SOT-23_Handsoldering; Part Number SSM3K341R,LF
R2, R4, R6, R7, R8, R10, R13, R14, R15, R16, R18, R19: 10k; R_0805_2012Metric_Pad1.20x1.40mm_HandSolder; Part Number RN73R2ATTD1002B25
R3, R5: BCS-102-L-D-HE; Samtec BCS Series; Part Number BCS-102-L-D-HE
R9, R11: HLE-104-02-F-DV-BE; Samtec HLE Series, through board; Part Number HLE-104-02-F-DV-BE
R21, R23: 1k; R_0805_2012Metric_Pad1.20x1.40mm_HandSolder; Part Number CRCW08051K00FKEA
SW1: Select Button; E-Switch TL3301 Series switch; Part Number TL3301SPF160QG
SW2: Start Button; E-Switch TL3301 Series switch; Part Number TL3301SPF160QG
SW3: Analog Button; SW_SPST_Omron_B3FS-100xP; Part Number B3FS-1000
U1: RaspberryPi_Pico; Raspberry Pi Pico Reduced Pin Footprint; Part Number SC0915
U2, U3: ADC088S022; TSSOP-16_4.4x5mm_P0.65mm; Part Number ADC088S022CIMTX/NOPB

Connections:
+3.3V: C5.1, C7.1, C9.1, C10.1, C12.1, C14.1, C15.1, C16.1, JOY1.H1 (H+), JOY1.V1 (V+), JOY2.H1 (H+), JOY2.V1 (V+), R3.1, R3.2, R5.3, R5.4, R9.2, R9.4, R9.6, R9.8, R11.2, R11.4, R11.6, R11.8, U1.35 (ADC_VREF), U1.36 (3V3), U2.2 (Va), U2.13 (Vd), U3.2 (Va), U3.13 (Vd)
/Dev1_Cs: U1.12 (GPIO9), U2.1 (/CS)
/Dev2_Cs: U1.16 (GPIO12), U3.1 (/CS)
/Dev_Rx: U1.11 (GPIO8), U2.15 (Dout), U3.15 (Dout)
/Dev_Sck: U1.14 (GPIO10), U2.16 (SCLK), U3.16 (SCLK)
/Dev_Tx: U1.15 (GPIO11), U2.14 (Din), U3.14 (Din)
/Host_+3.5V: C2.1, D1.2 (A), J1.5
/Host_+8V: C6.1, C11.1, J1.3, M1.1 (+), M2.1 (+)
/Host_Ack: J1.9, U1.26 (GPIO20)
/Host_Atn: J1.6, U1.22 (GPIO17)
/Host_Clk: J1.7, U1.24 (GPIO18)
/Host_Cmd: J1.2, U1.21 (GPIO16)
/Host_Dat: J1.1, U1.25 (GPIO19)
/JOY_L_H: JOY2.H2 (H), U2.9 (IN5)
/JOY_L_V: JOY2.V2 (V), U2.10 (IN6)
/JOY_R_H: JOY1.H2 (H), U3.8 (IN4)
/JOY_R_V: JOY1.V2 (V), U3.7 (IN3)
/L_Motor: R23.1, U1.32 (GPIO27_ADC1)
/R_Motor: R21.2, U1.1 (GPIO0)
/SW_ANA: C4.1, SW3.1, U1.29 (GPIO22)
/SW_CIR: R11.7, R19.2, U3.4 (IN0)
/SW_CRS: R11.5, R16.2, U3.9 (IN5)
/SW_DDN: R9.5, R15.1, U2.11 (IN7)
/SW_DLE: R9.3, R13.1, U2.6 (IN2)
/SW_DRT: R9.7, R18.1, U2.4 (IN0)
/SW_DUP: R8.1, R9.1, U2.5 (IN1)
/SW_L1: R3.4, R6.1, U2.7 (IN3)
/SW_L2: R2.1, R3.3, U2.8 (IN4)
/SW_L3: C13.1, JOY2.S1 (SW+), U1.34 (GPIO28_ADC2)
/SW_R1: R5.2, R7.2, U3.10 (IN6)
/SW_R2: R4.2, R5.1, U3.11 (IN7)
/SW_R3: C8.1, JOY1.S1 (SW+), U1.4 (GPIO2)
/SW_SEL: C1.1, SW1.2, U1.31 (GPIO26_ADC0)
/SW_SQU: R11.3, R14.2, U3.6 (IN2)
/SW_STA: C3.1, SW2.2, U1.10 (GPIO7)
/SW_TRI: R10.2, R11.1, U3.5 (IN1)
GND: C1.2, C2.2, C3.2, C4.2, C5.2, C7.2, C8.2, C9.2, C10.2, C12.2, C13.2, C14.2, C15.2, C16.2, J1.4, JOY1.H3 (H-), JOY1.MT, JOY1.S2 (SW-), JOY1.V3 (V-), JOY2.H3 (H-), JOY2.MT, JOY2.S2 (SW-), JOY2.V3 (V-), Q1.2 (S), Q2.2 (S), R2.2, R4.1, R6.2, R7.1, R8.2, R10.1, R13.2, R14.1, R15.2, R16.1, R18.2, R19.1, SW1.1, SW2.1, SW3.2, U1.3 (GND), U1.8 (GND), U1.13 (GND), U1.18 (GND), U1.23 (GND), U1.28 (GND), U1.33 (AGND), U1.38 (GND), U2.3 (AGND), U2.12 (DGND), U3.3 (AGND), U3.12 (DGND)
unnamed: D1.1 (K), U1.39 (VSYS)
unnamed: C6.2, M1.2 (-), Q1.3 (D)
unnamed: C11.2, M2.2 (-), Q2.3 (D)
unnamed: Q1.1 (G), R21.1
unnamed: Q2.1 (G), R23.2

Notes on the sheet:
Red
Yellow
White
Blue
Grey
Orange
Brown
Green
Black
Notes: 1. Connector J1 is laid out in the same order as the host connector. It is possible that a cable harvested from an OEM controller will not have the same pinout as this header, and will need to be repinned.

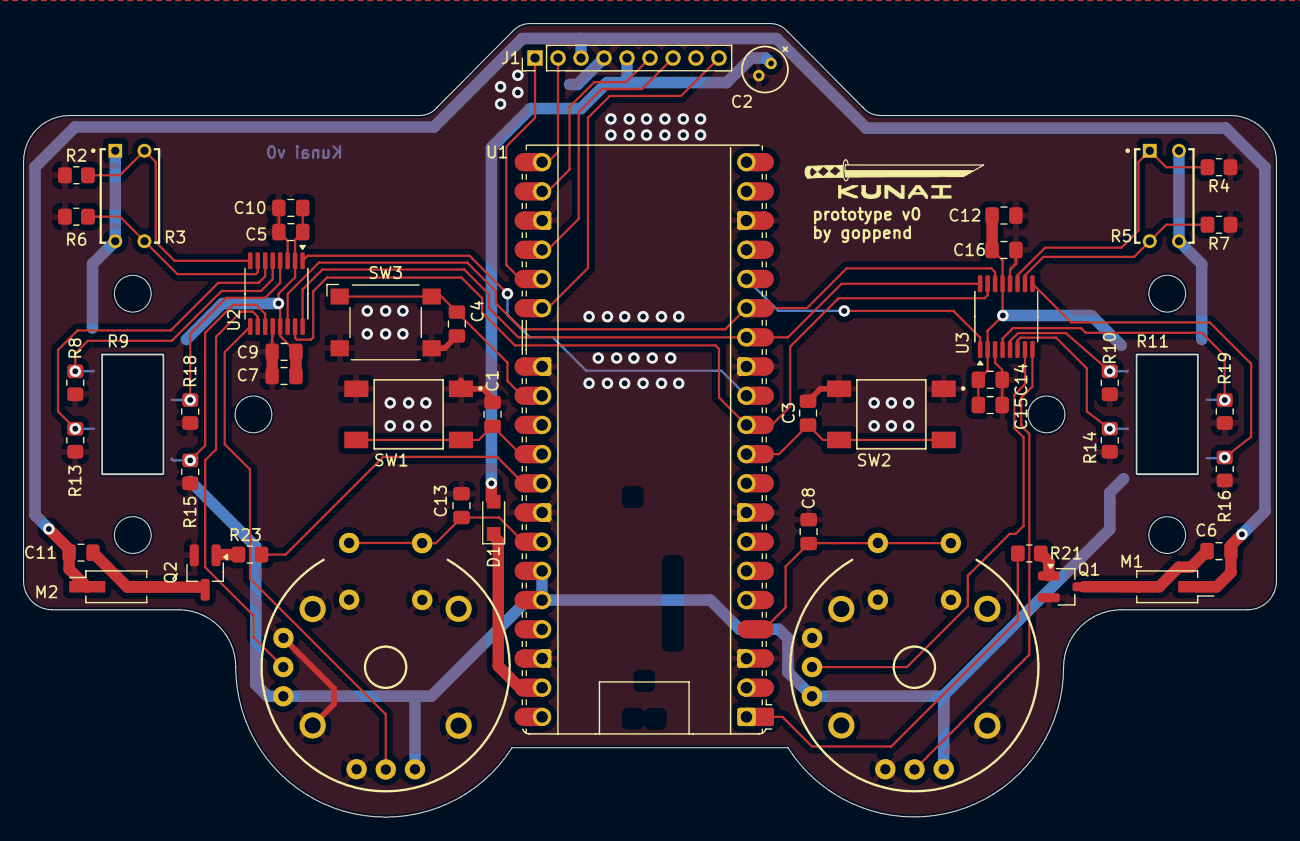
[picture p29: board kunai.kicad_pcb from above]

Board: 2 copper layers, 109.0 x 69.0 mm, 48 parts (0 on the bottom side), 42 nets.

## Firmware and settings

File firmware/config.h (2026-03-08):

// define pin connections
#define GPIO_L3         0
#define GPIO_R3         1
#define GPIO_START      2
#define GPIO_L_MOTOR    3
#define GPIO_R_MOTOR    4
#define GPIO_LED        23
#define GPIO_SELECT     24
#define GPIO_ANALOG     25

#ifdef DIGITAL_INPUTS
    // define digital inputs
    #define GPIO_FACE_SQUARE    5
    #define GPIO_FACE_CROSS     6
    #define GPIO_FACE_CIRCLE    7
    #define GPIO_FACE_TRIANGLE  8
    #define GPIO_SHOULDER_R2    9
    #define GPIO_SHOULDER_R1    10
    #define GPIO_SHOULDER_L2    17
    #define GPIO_SHOULDER_L1    18
    #define GPIO_DPAD_UP        19
    #define GPIO_DPAD_LEFT      20
    #define GPIO_DPAD_RIGHT     21
    #define GPIO_DPAD_DOWN      22
    #define GPIO_ANA_R_Y        26
    #define GPIO_ANA_R_X        27
    #define GPIO_ANA_L_Y        28
    #define GPIO_ANA_L_X        29
#else
    // define pins for external ADCs
    #define GPIO_LEFT_ADC   9 // adc 1
    #define GPIO_RIGHT_ADC  12 // adc 2
    #define SPI_DEV_RX      8
    #define SPI_DEV_SCK     10
    #define SPI_DEV_TX      11
#endif

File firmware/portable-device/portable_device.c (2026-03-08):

#include "pico/stdio.h"
#include "hardware/spi.h"
#include "hardware/pwm.h"
#include "hardware/adc.h"

#include "controller_simulator.h"
#include "portable_device.h"
#include "config.h"

// Table correlating pins to their function or I/O direction
static uint8_t gpio_table[] = {
#ifdef DIGITAL_INPUTS
    GPIO_DPAD_UP,       GPIO_FUNC_NULL, GPIO_IN,
    GPIO_DPAD_DOWN,     GPIO_FUNC_NULL, GPIO_IN,
    GPIO_DPAD_LEFT,     GPIO_FUNC_NULL, GPIO_IN,
    GPIO_DPAD_RIGHT,    GPIO_FUNC_NULL, GPIO_IN,
    GPIO_FACE_TRIANGLE, GPIO_FUNC_NULL, GPIO_IN,
    GPIO_FACE_SQUARE,   GPIO_FUNC_NULL, GPIO_IN,
    GPIO_FACE_CIRCLE,   GPIO_FUNC_NULL, GPIO_IN,
    GPIO_FACE_CROSS,    GPIO_FUNC_NULL, GPIO_IN,
    GPIO_SHOULDER_L1,   GPIO_FUNC_NULL, GPIO_IN,
    GPIO_SHOULDER_L2,   GPIO_FUNC_NULL, GPIO_IN,
    GPIO_SHOULDER_R1,   GPIO_FUNC_NULL, GPIO_IN,
    GPIO_SHOULDER_R2,   GPIO_FUNC_NULL, GPIO_IN,
    GPIO_ANA_R_Y,       GPIO_FUNC_SIO,  GPIO_IN,
    GPIO_ANA_R_X,       GPIO_FUNC_SIO,  GPIO_IN,
    GPIO_ANA_L_Y,       GPIO_FUNC_SIO,  GPIO_IN,
    GPIO_ANA_L_X,       GPIO_FUNC_SIO,  GPIO_IN,
#else
    GPIO_LEFT_ADC,      GPIO_FUNC_NULL, GPIO_OUT,
    GPIO_RIGHT_ADC,     GPIO_FUNC_NULL, GPIO_OUT,
    SPI_DEV_RX,         GPIO_FUNC_SPI, 0,
    SPI_DEV_TX,         GPIO_FUNC_SPI, 0,
    SPI_DEV_SCK,        GPIO_FUNC_SPI, 0,
#endif
    GPIO_L_MOTOR,       GPIO_FUNC_PWM, 0,
    GPIO_R3,            GPIO_FUNC_NULL, GPIO_IN,
    GPIO_START,         GPIO_FUNC_NULL, GPIO_IN,
    GPIO_ANALOG,        GPIO_FUNC_NULL, GPIO_IN,
    GPIO_LED,           GPIO_FUNC_NULL, GPIO_OUT,
    GPIO_SELECT,        GPIO_FUNC_NULL, GPIO_IN,
    GPIO_L_MOTOR,       GPIO_FUNC_NULL, GPIO_OUT,
    GPIO_L3,            GPIO_FUNC_NULL, GPIO_IN
};

// static variables
static uint pwm_slice_num;
static bool mode_state_change_flag = false;

// the array containing the last smoothed analog input
// Each index is for a different input.
static uint8_t analog_smooth[ANALOG_CHANNELS];

// read from an ADC on the SPI bus.
// adc_select - which ADC to select, ignored when DIGITAL_INPUTS is defined
// channel - the channel to read from
// returns the resultant byte read from the ADC
uint8_t read_adc(uint8_t adc_select, uint8_t channel) {
#ifdef DIGITAL_INPUTS
    adc_select_input(channel);
    return adc_read() >> 4;
#else
    uint8_t address = channel << 3;
    uint8_t result[2];

    // select an ADC
    gpio_put(GPIO_LEFT_ADC, adc_select != 1); 
    gpio_put(GPIO_RIGHT_ADC, adc_select != 2);

    // set the channel
    spi_write_blocking(spi1, &address, 2);

    // deselect both ADCs
    gpio_put(GPIO_LEFT_ADC, 1);
    gpio_put(GPIO_RIGHT_ADC, 1);

    // select an ADC
    gpio_put(GPIO_LEFT_ADC, adc_select != 1); 
    gpio_put(GPIO_RIGHT_ADC, adc_select != 2);

    // read the value from it
    spi_read_blocking(spi1, 0, result, 2);
    
    // deselect both ADCs
    gpio_put(GPIO_LEFT_ADC, 1);
    gpio_put(GPIO_RIGHT_ADC, 1);

    return result[0]<<4 | result[1]>>4;
#endif
}

// Perform an exponential smoothing algorithm on raw ADC values
// next - the next contributing value
// button_ix - the input index
// returns a smoothed value for this input
uint8_t exponential_smooth(uint8_t next, uint8_t button_ix) {
    analog_smooth[button_ix] = ALPHA*next + (1 - ALPHA)*analog_smooth[button_ix];
    return analog_smooth[button_ix];
}

// Init everything needed for the portable
void portable_device_init() {
    // init digital IO
    spi_init(spi1, 1000 * 1000); // init device SPI bus at 1 MHz
    adc_init();

    gpio_set_function(GPIO_R_MOTOR, GPIO_FUNC_PWM);
    uint pwm_slice_num = pwm_gpio_to_slice_num(GPIO_R_MOTOR);
    pwm_config config = pwm_get_default_config();
    pwm_config_set_clkdiv(&config, 4.f);
    pwm_init(pwm_slice_num, &config, false);

    for (int gpio_table_index = 0; gpio_table_index < sizeof(gpio_table) / 3; gpio_table_index++ )
    {
        switch(gpio_table[gpio_table_index * 3 + 1])
        {
            case GPIO_FUNC_NULL:
            {
                // Init GPIOs with no hardware function
                gpio_init(gpio_table[gpio_table_index * 3]);
                gpio_set_dir(gpio_table[gpio_table_index * 3], gpio_table[gpio_table_index * 3 + 2]);

                if (gpio_table[gpio_table_index * 3 + 2] == GPIO_OUT)
                {
                    // set the initial state for outputs to be low
                    gpio_put(gpio_table[gpio_table_index * 3], 0);
                }
                else
                {
                    // set pull up resistor on inputs
                    gpio_pull_up(gpio_table[gpio_table_index * 3]);
                }
                break;
            }
            case GPIO_FUNC_SIO:
            {
                // init analog inputs
                gpio_set_dir(gpio_table[gpio_table_index * 3], gpio_table[gpio_table_index * 3 + 2]);
                gpio_set_function(gpio_table[gpio_table_index * 3], GPIO_FUNC_SIO);
                gpio_disable_pulls(gpio_table[gpio_table_index * 3]);
                gpio_set_input_enabled(gpio_table[gpio_table_index * 3], false);
                break;
            }
            case GPIO_FUNC_SPI:
            {
                // init SPI
                gpio_set_function(gpio_table[gpio_table_index * 3], GPIO_FUNC_SPI);
                break;
            }
            case GPIO_FUNC_PWM:
            {
                // init PWM output for e.g. rumble
                gpio_set_function(gpio_table[gpio_table_index * 3], GPIO_FUNC_PWM);
                pwm_slice_num = pwm_gpio_to_slice_num(gpio_table[gpio_table_index * 3]);
                pwm_config config = pwm_get_default_config();
                pwm_config_set_clkdiv(&config, 4.f);
                pwm_init(pwm_slice_num, &config, false);
                break;
            }
        }
    }
}
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

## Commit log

2025-10-12 First commit, v0 hardware and firmware
    [BCS-102-L-D-HE.stp, COM-09032.step, ECE-A1EKA100.step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]
2025-10-25 Add module PCB
    [ABM8-272-T3.step, kunai-mod.kicad_pcb, kunai-mod.kicad_sch]
2025-10-25 Add footprint and update readme, small tweaks to pcb/schematic.
    [kunai-mod.kicad_pcb, kunai-mod.kicad_sch]
2025-10-26 Add prototype firmware support for module.
2026-03-08 Update firmware, cleaned up for module, remove prototype stuff.

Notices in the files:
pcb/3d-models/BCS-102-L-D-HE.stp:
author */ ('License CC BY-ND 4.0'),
